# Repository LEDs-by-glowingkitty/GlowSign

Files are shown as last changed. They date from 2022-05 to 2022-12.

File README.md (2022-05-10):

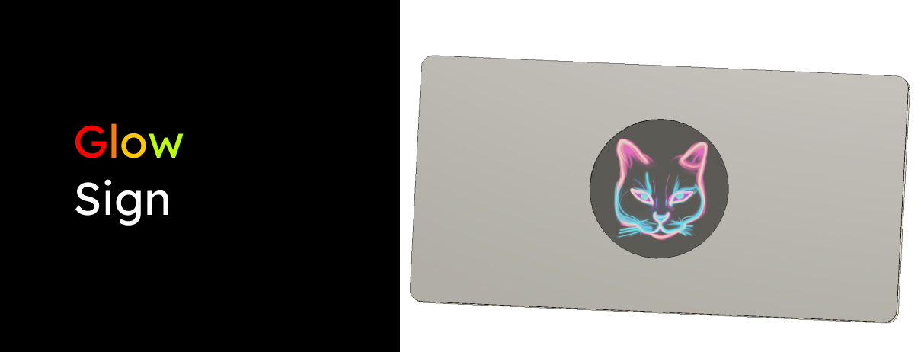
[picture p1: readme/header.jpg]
GlowSign


## Warning:

This project is currently under active development and has not been fully tested yet. If you decide to build or clone the project, be aware it might not work yet as expected. Use at your own risk.

## What is this project?

A battery powered LED sign for your laptop, or where ever else you want to use it!

## Links

- [Main PCB files](https://github.com/glowingkitty/GlowKittySign/tree/main/Main%20PCB)
- [Aluminum Cover PCB - Cat Edition files](https://github.com/glowingkitty/GlowKittySign/tree/main/AluminumCover%20PCB%20cat%20edition)

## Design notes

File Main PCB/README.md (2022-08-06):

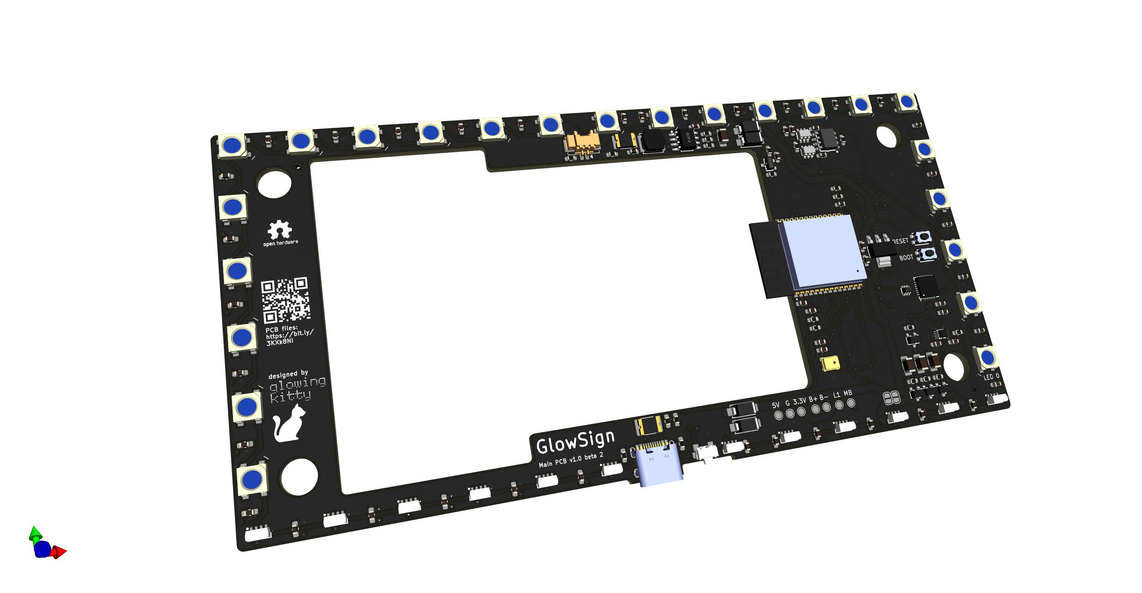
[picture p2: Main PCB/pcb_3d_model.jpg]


# GlowSign Main PCB

The main PCB for GlowSign. With all the LEDs, the integrated ESP32, a microphone to make the LED animations react to music - and it runs GlowOS (my WLED fork). But you can also upload your own software to the ESP32. The PCB can be powered via USB-C and via a lipo battery.

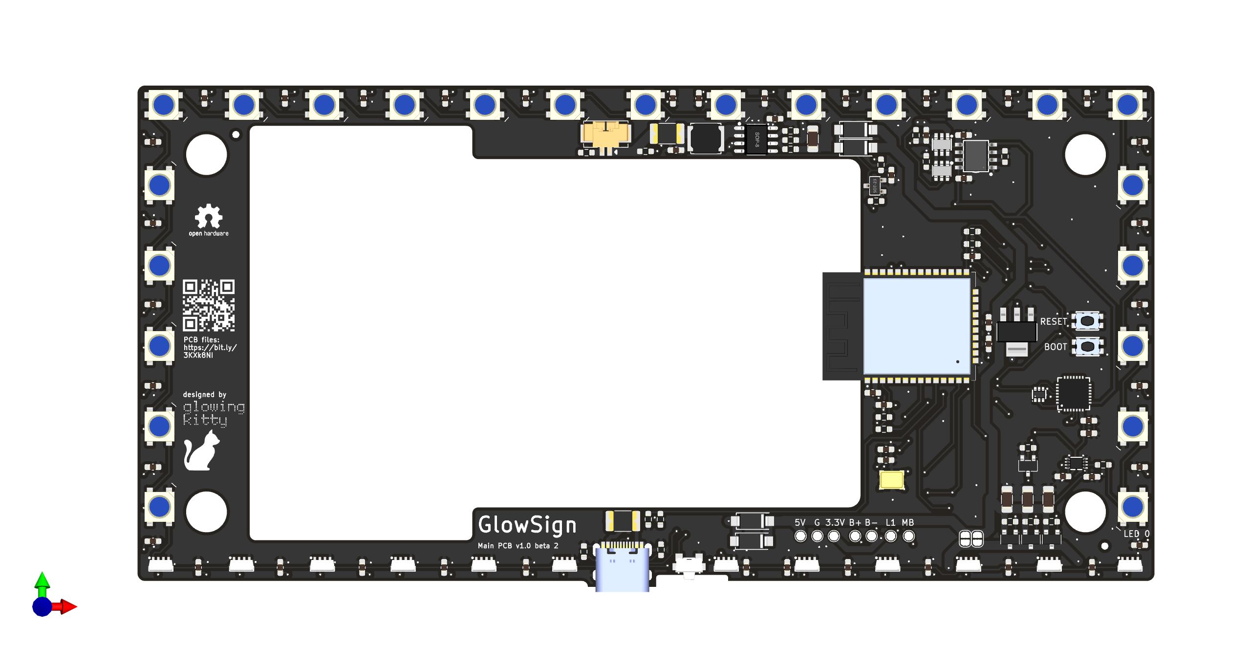
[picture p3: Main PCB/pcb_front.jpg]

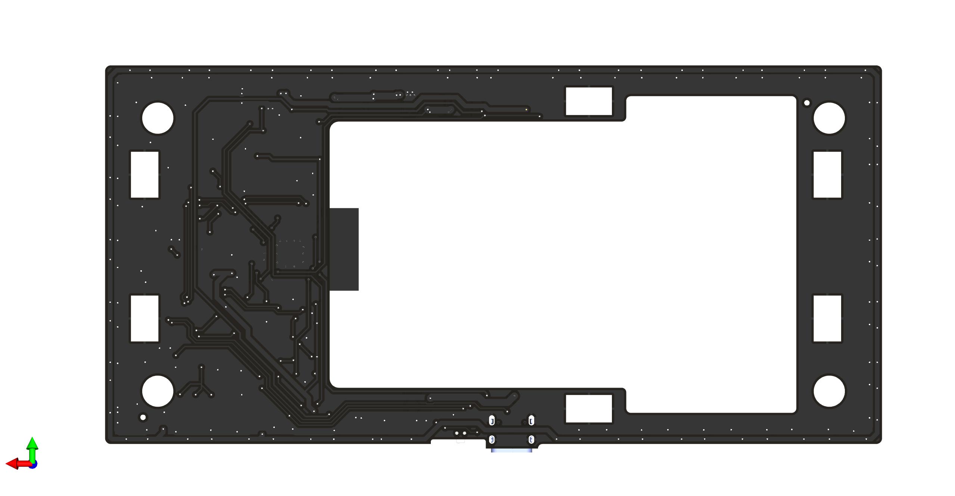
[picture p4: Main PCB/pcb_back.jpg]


## Links

- [Schematic](https://github.com/glowingkitty/GlowSign/blob/main/Main%20PCB/GlowSignMainPCB.pdf)
- [Interactive BOM](https://htmlpreview.github.io/?https://github.com/glowingkitty/GlowSign/blob/main/Main%20PCB/bom/ibom.html)

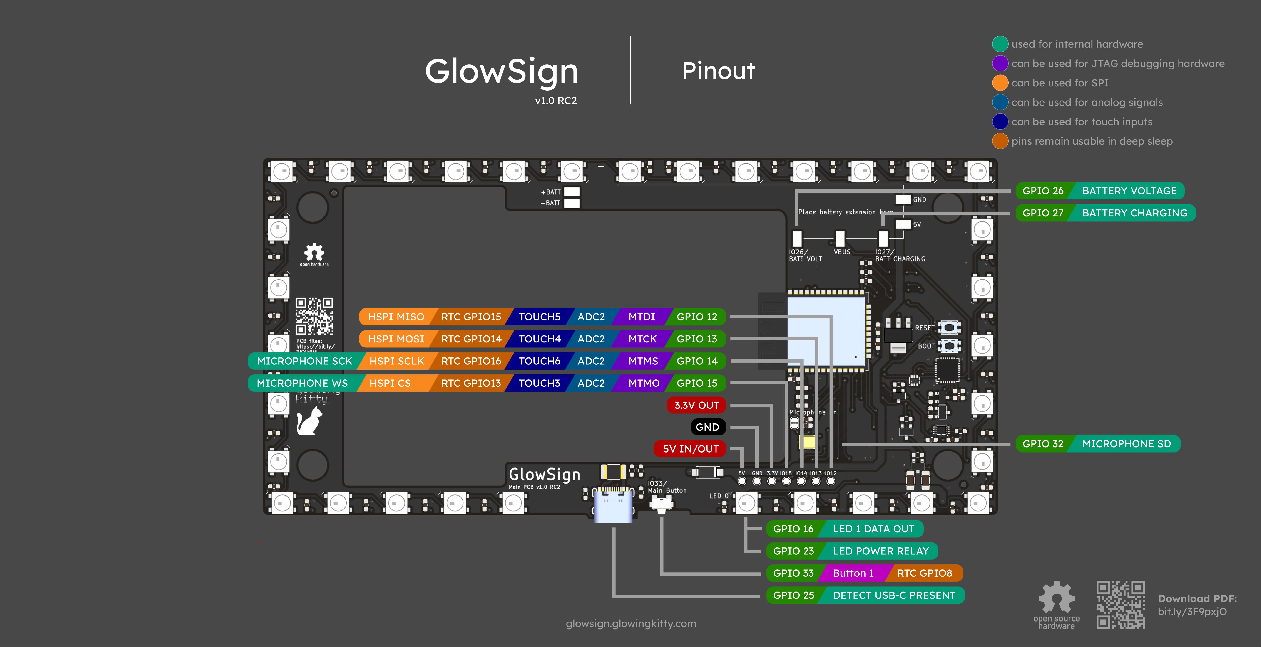
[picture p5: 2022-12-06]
documents/pinout GlowSign v1.0 RC2.jpg

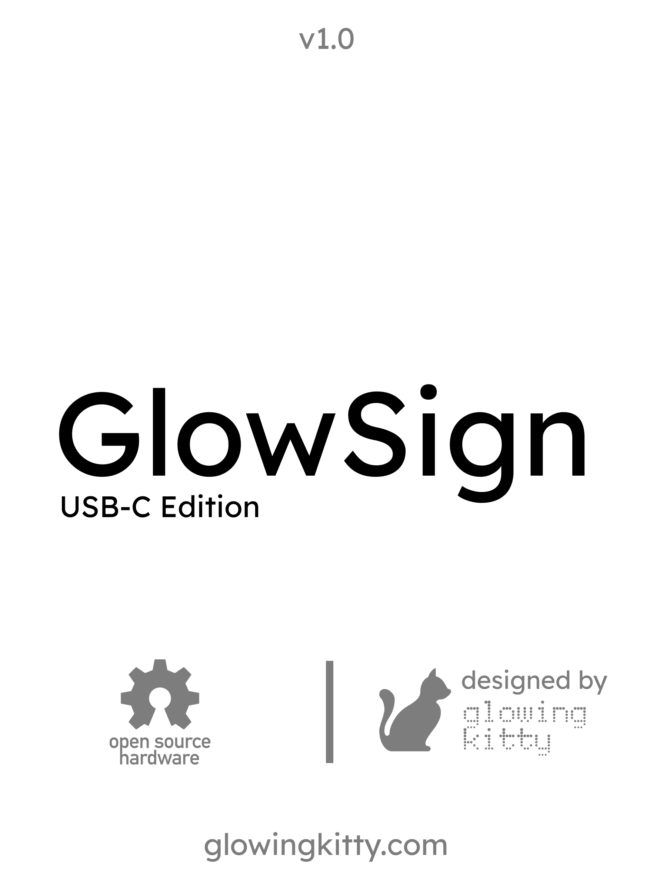
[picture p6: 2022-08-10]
GlowSign USB-C Sticker Back @300dpi (Page 1).png

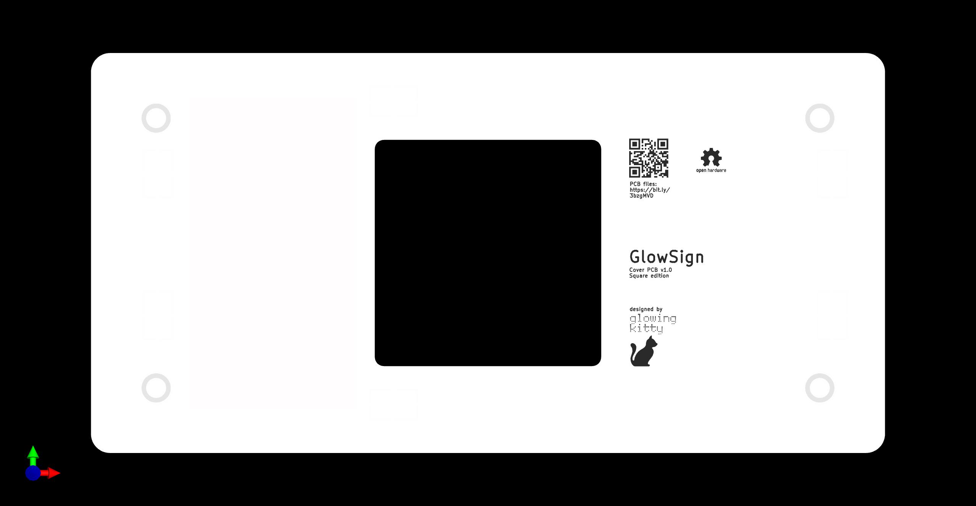
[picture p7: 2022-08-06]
Cover PCB Square Edition/pure_pcb_front.jpg

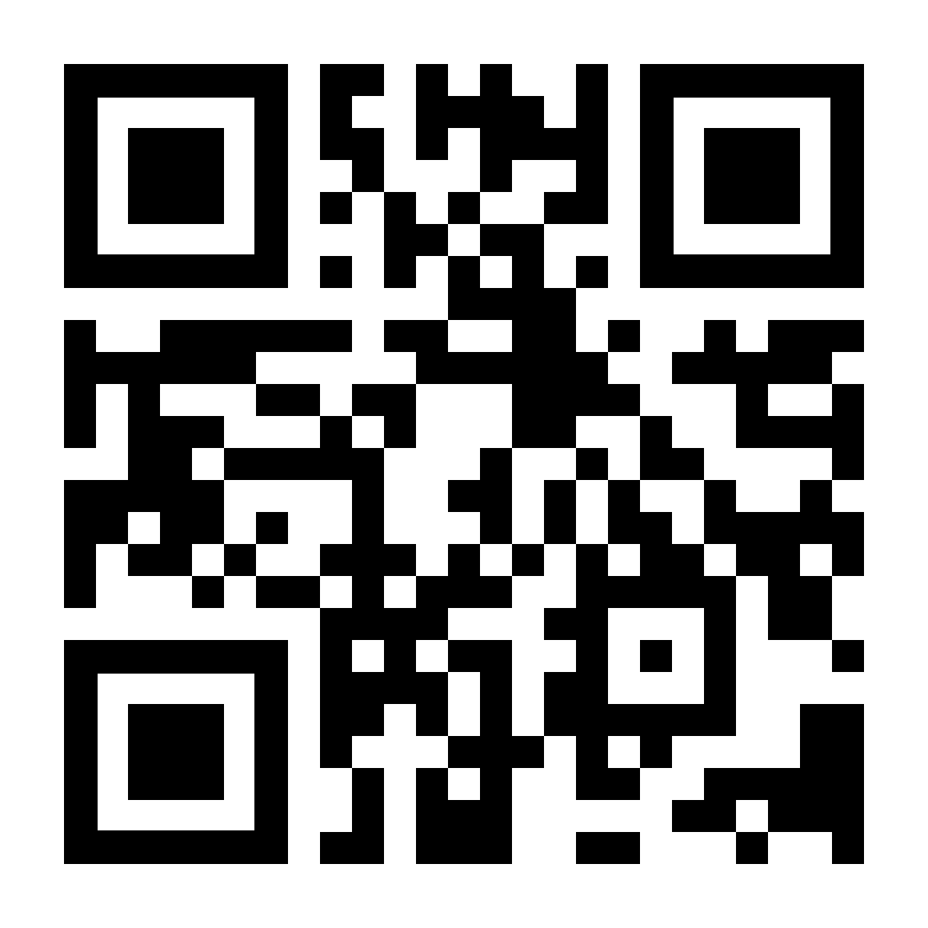
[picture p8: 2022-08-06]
Cover PCB Circle Edition/glowsign cover pcb circle pcb files.png

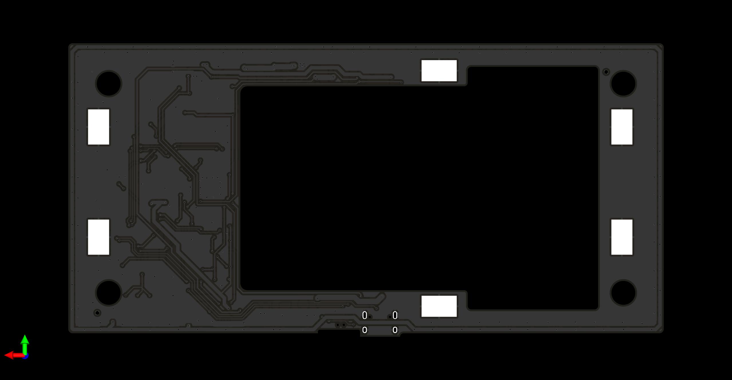
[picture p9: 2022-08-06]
Main PCB/pure_pcb_back.jpg

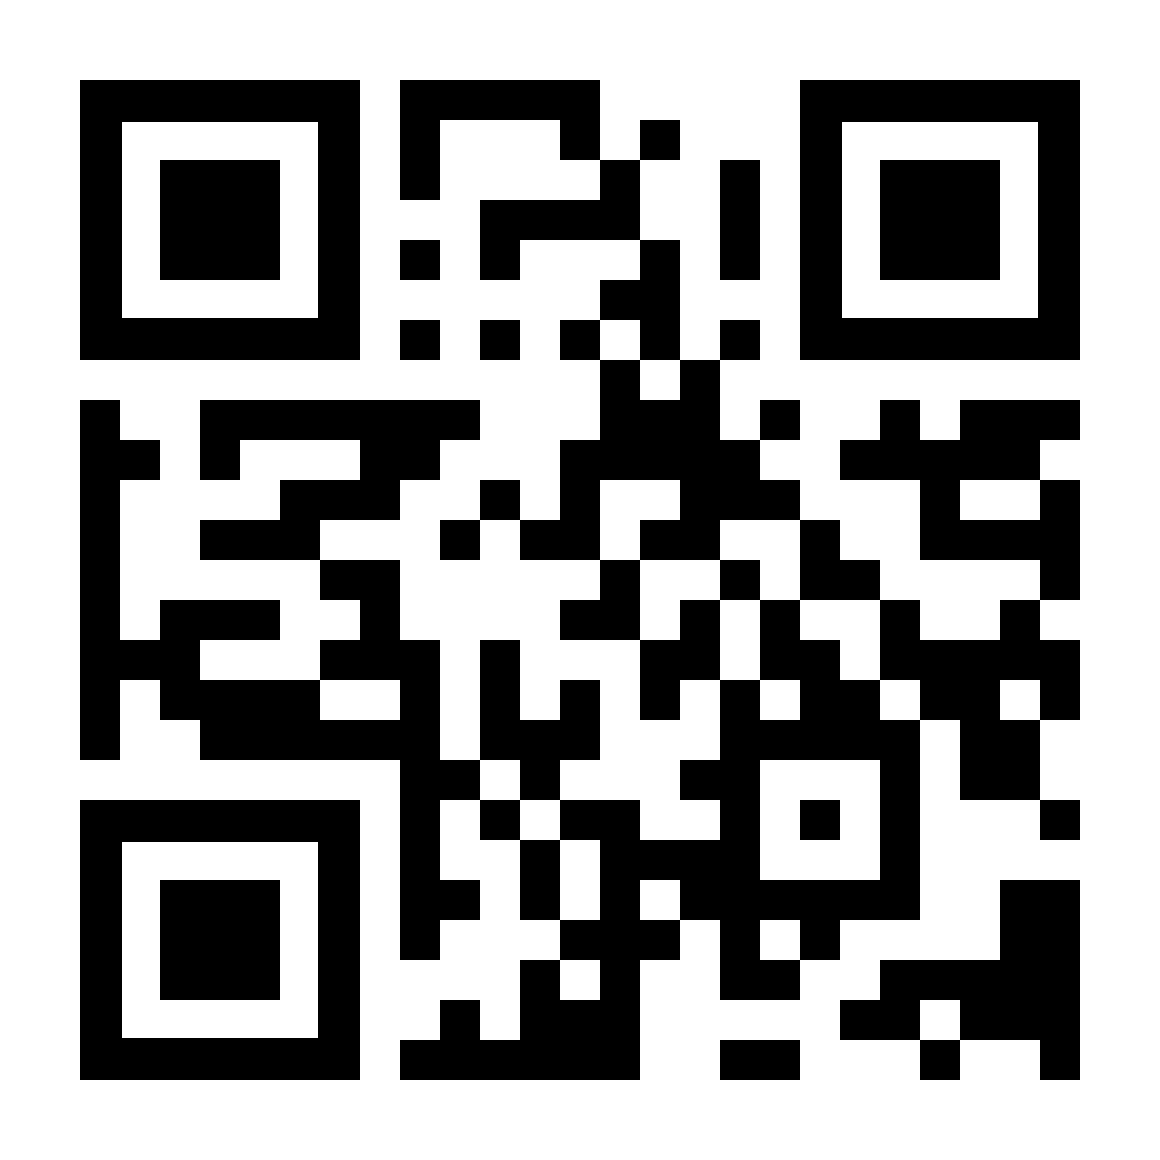
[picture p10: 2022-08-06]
Cover PCB Square Edition/glowsign cover square pcb files.png

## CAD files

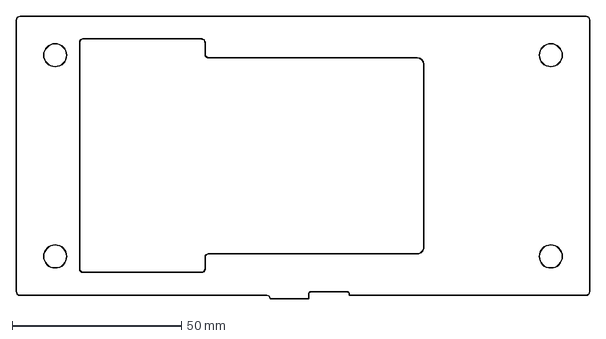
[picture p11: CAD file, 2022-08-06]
Main PCB/main_pcb_cutout.dxf
169.5 x 83.5 mm

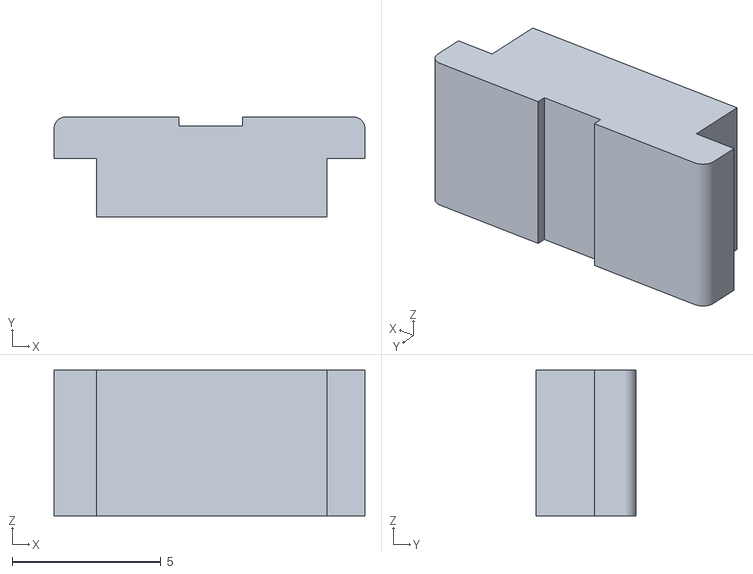
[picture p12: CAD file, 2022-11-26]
3D printed parts/main button.stl
10.4 x 3.37 x 4.89

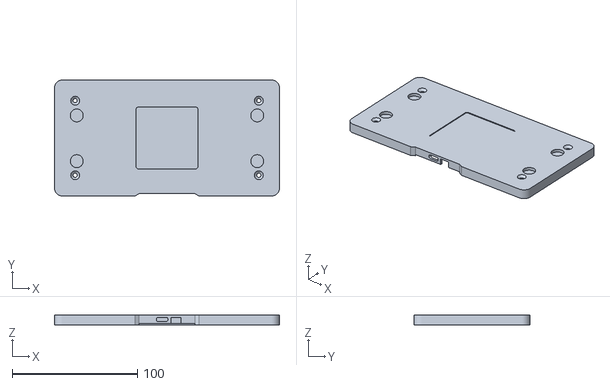
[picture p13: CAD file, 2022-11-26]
3D printed parts/case usb c only.stl
179.5 x 92.5 x 7.99

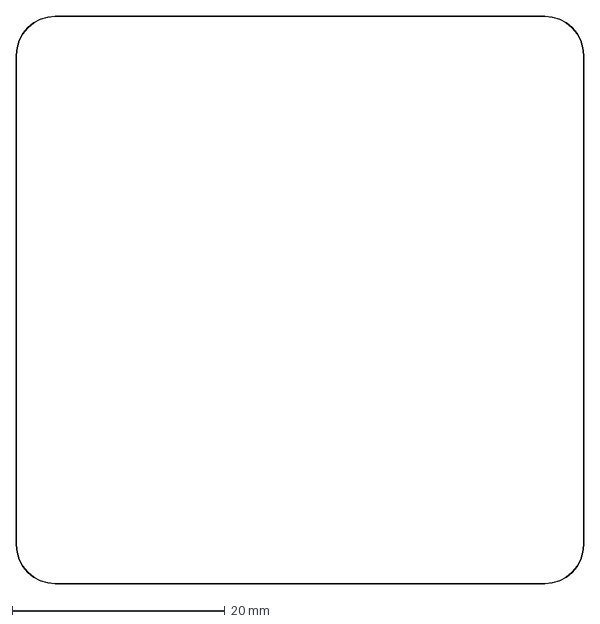
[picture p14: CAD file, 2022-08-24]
acrylic_plate_cutout.dxf
53.3 x 53.3 mm

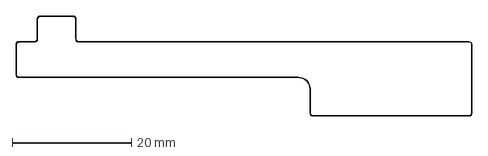
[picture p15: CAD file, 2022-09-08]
Battery Extension PCB/PCB cutout.dxf
76.5 x 16.7 mm

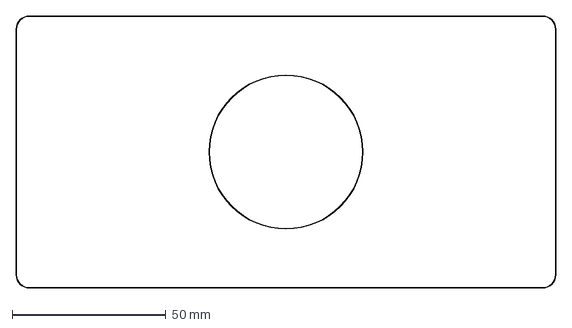
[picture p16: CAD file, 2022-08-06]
Cover PCB Circle Edition/aluminum_pcb_cutout_round.dxf
175.4 x 88.4 mm

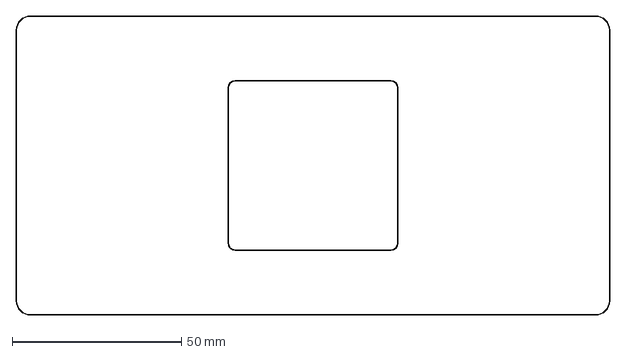
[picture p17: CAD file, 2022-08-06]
Cover PCB Square Edition/aluminum_pcb_cutout_square.dxf
175.4 x 88.4 mm

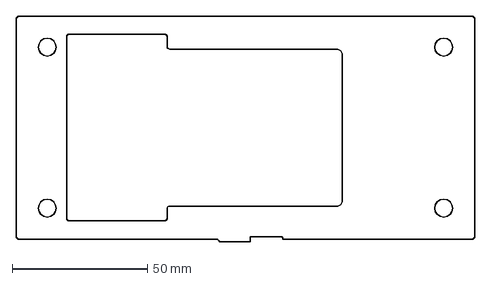
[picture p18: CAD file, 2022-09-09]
Main PCB/pcb_cutout.dxf
169.5 x 83.5 mm

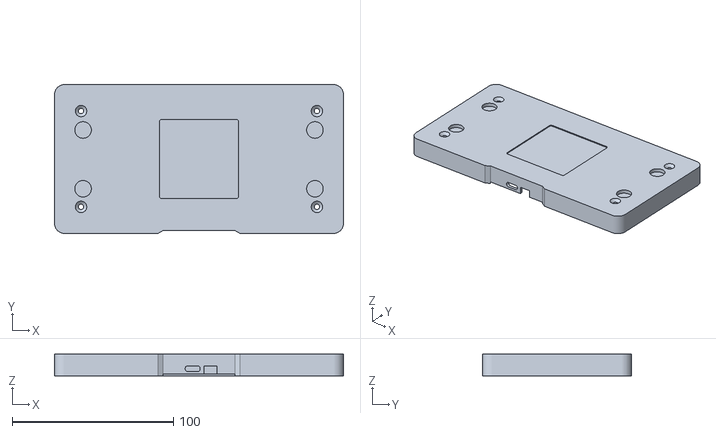
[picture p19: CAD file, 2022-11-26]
3D printed parts/case usb c and battery.stl
179.5 x 92.5 x 13.6

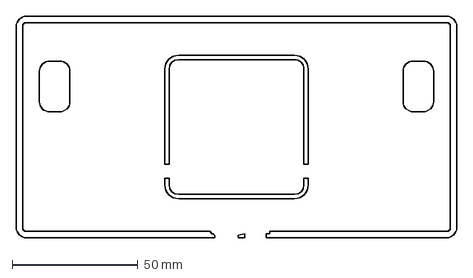
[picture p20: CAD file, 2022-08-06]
Main PCB/case_surrounding_pcb.dxf
175.0 x 88.0 mm

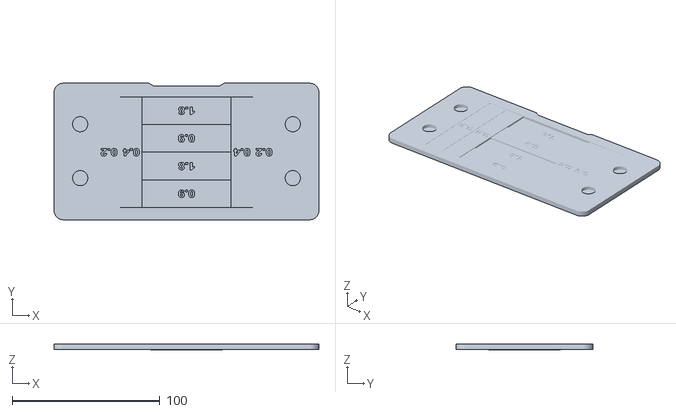
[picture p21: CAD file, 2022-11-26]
3D printed parts/magnetic dock.stl
179.5 x 92.5 x 4.30

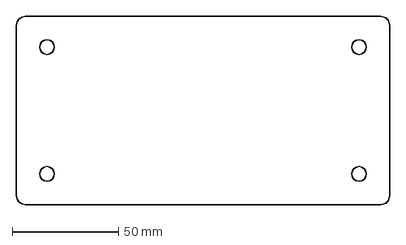
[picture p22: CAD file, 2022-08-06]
Cover PCB Circle Edition/aluminum_pcb_smd_nut_positions.dxf
175.4 x 88.4 mm

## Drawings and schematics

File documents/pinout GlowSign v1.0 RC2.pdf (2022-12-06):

GlowSign | Pinout

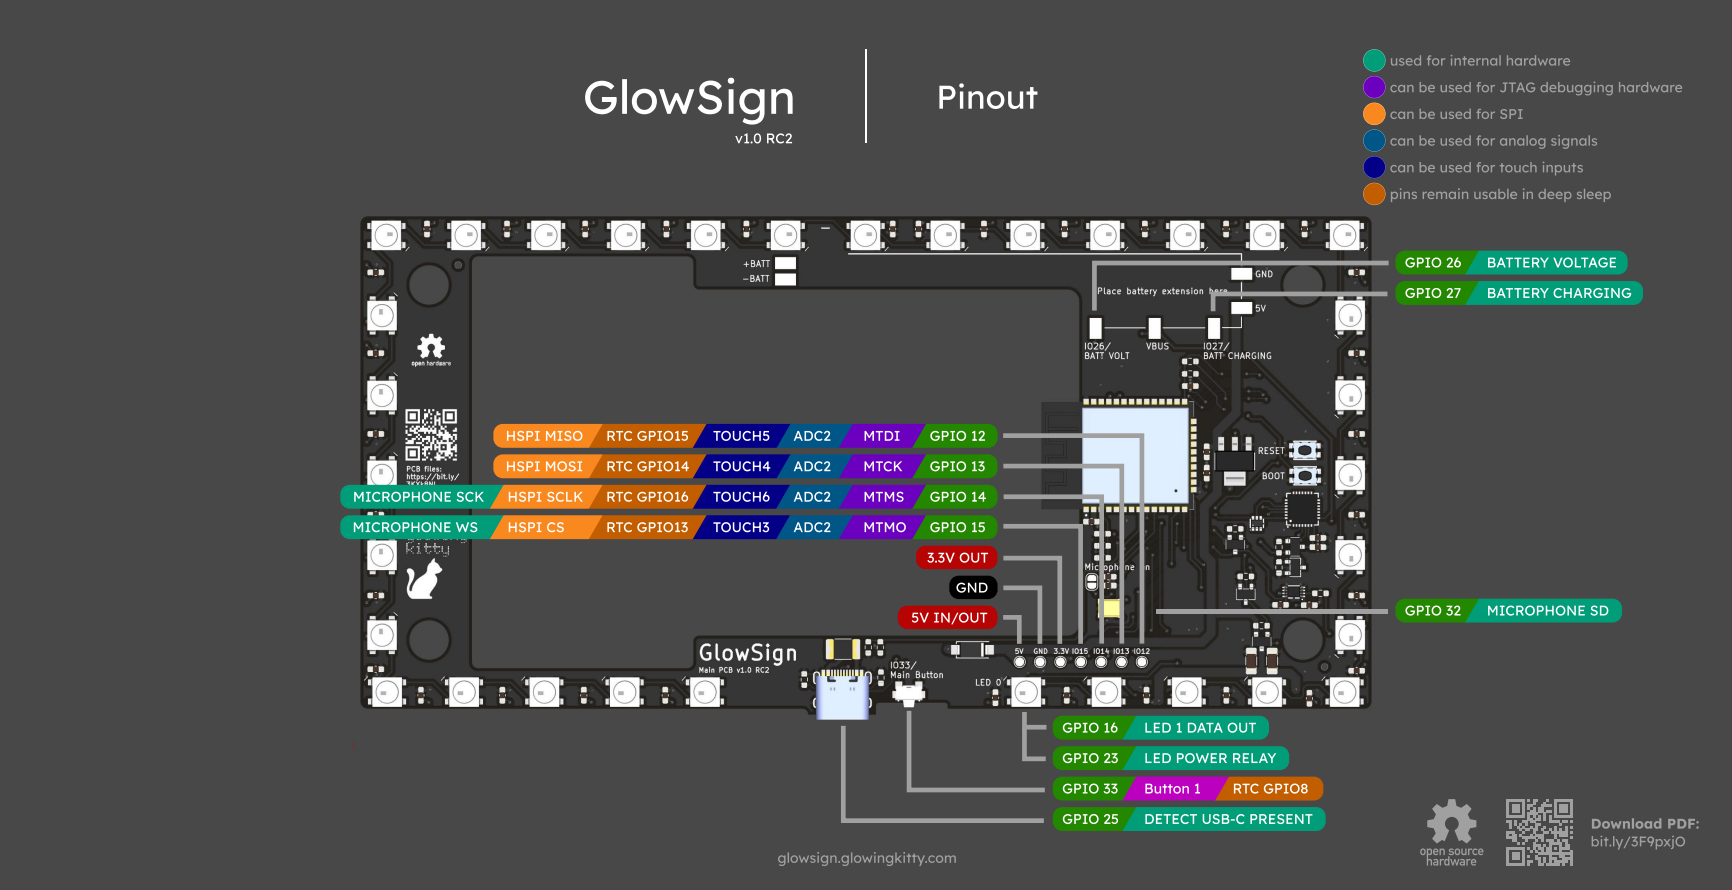
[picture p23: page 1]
GPIO 33; Button 1; RTC GPIO8; GPIO 23; LED POWER RELAY; GPIO 16; LED 1 DATA OUT; GPIO 32; MICROPHONE SD; GPIO 25; DETECT USB-C PRESENT; GPIO 26; BATTERY VOLTAGE; GPIO 27; BATTERY CHARGING; 3.3V OUT; 5V IN/OUT; GND; MICROPHONE SCK; HSPI SCLK; RTC GPIO16; TOUCH6; ADC2; MTMS; GPIO 14; MICROPHONE WS; HSPI CS; RTC GPIO13; TOUCH3; MTMO; GPIO 15; HSPI MISO; RTC GPIO15; TOUCH5; MTDI; GPIO 12; HSPI MOSI; RTC GPIO14; TOUCH4; MTCK; GPIO 13; Download PDF: bit.ly/3F9pxjO

used for internal hardware

can be used for JTAG debugging hardware

can be used for SPI

can be used for analog signals

can be used for touch inputs

pins remain usable in deep sleep

glowsign.glowingkitty.com

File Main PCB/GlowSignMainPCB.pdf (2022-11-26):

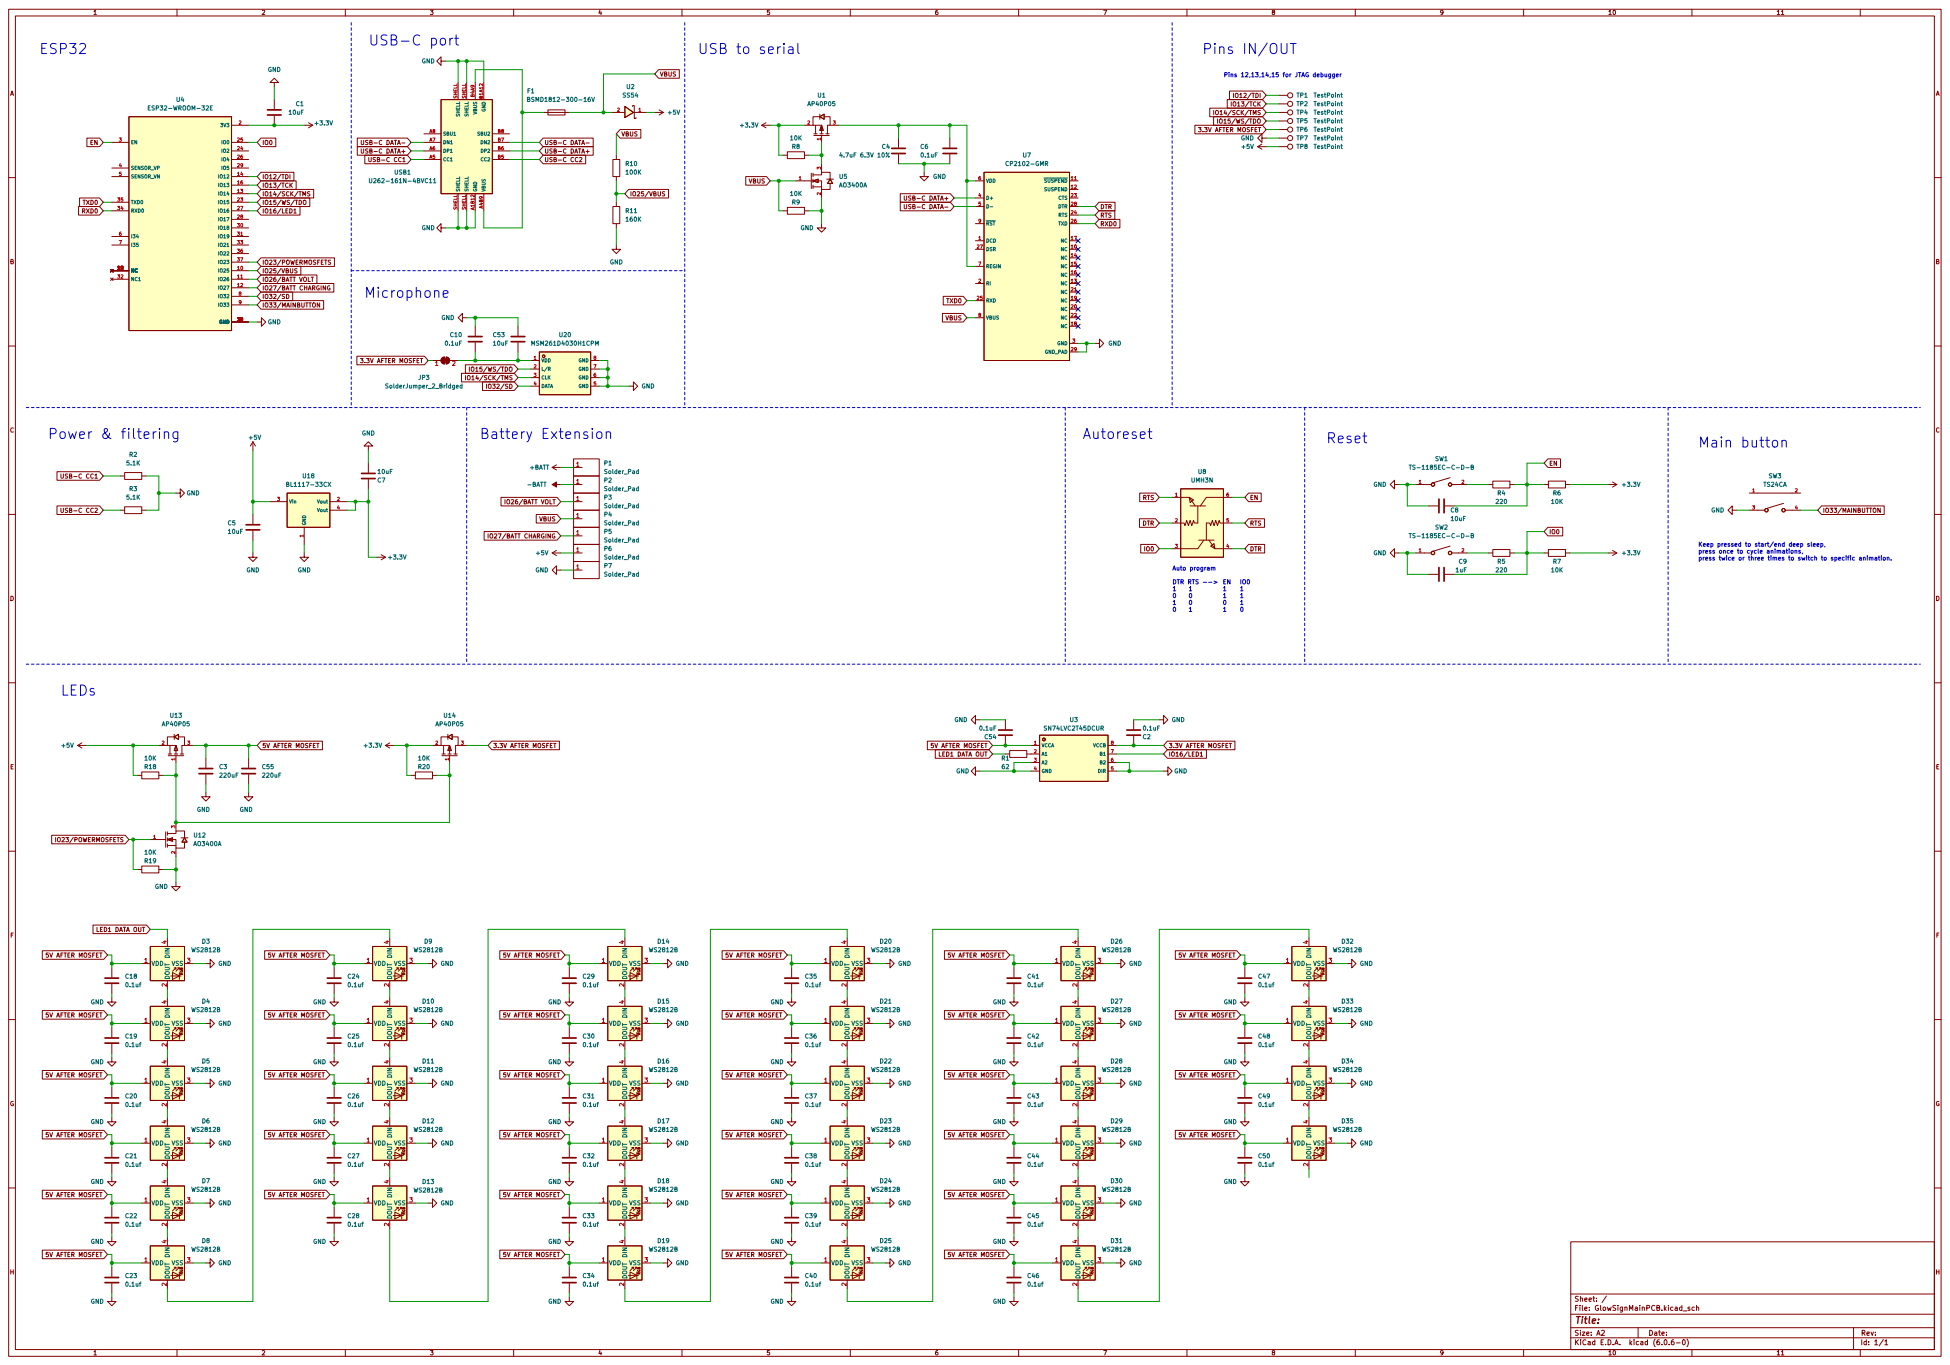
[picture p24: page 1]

USB to serial USB-C port ESP32

Pins 12,13,14,15 for JTAG debugger

4D14 WS2812BGND GND A1B12 VBUS A4B9 CC1 A5 DP1 A6 DN1 A7 SBU1 A8 GND B1A12 VBUS B4A9 CC2 B5 DP2 B6 DN2 B7 SBU2 B8 SHELL SHELL SHELL SHELL SHELL SHELL SHELL SHELL USB1 U262-161N-4BVC11 RGB VDD 1 DOUT

USB-C DATA+ USB-C CC1 USB-C DATA-

GND
3.3V AFTER MOSFET RTS DTR

1 Vout 2 Vin 3 Vout 4 U18 BL1117-33CX GND

Keep pressed to start/end deep sleep,
press once to cycle animations,
press twice or three times to switch to specific animation.

3 DIN
GND GND RGB VDD

4D10 WS2812BGND GND RGB VDD 1 DOUT

4D4 WS2812B GND RGB VDD 1 DOUT

4D28 WS2812B GND RGB VDD 1 DOUT

4D8 WS2812B GND RGB VDD 1 DOUT

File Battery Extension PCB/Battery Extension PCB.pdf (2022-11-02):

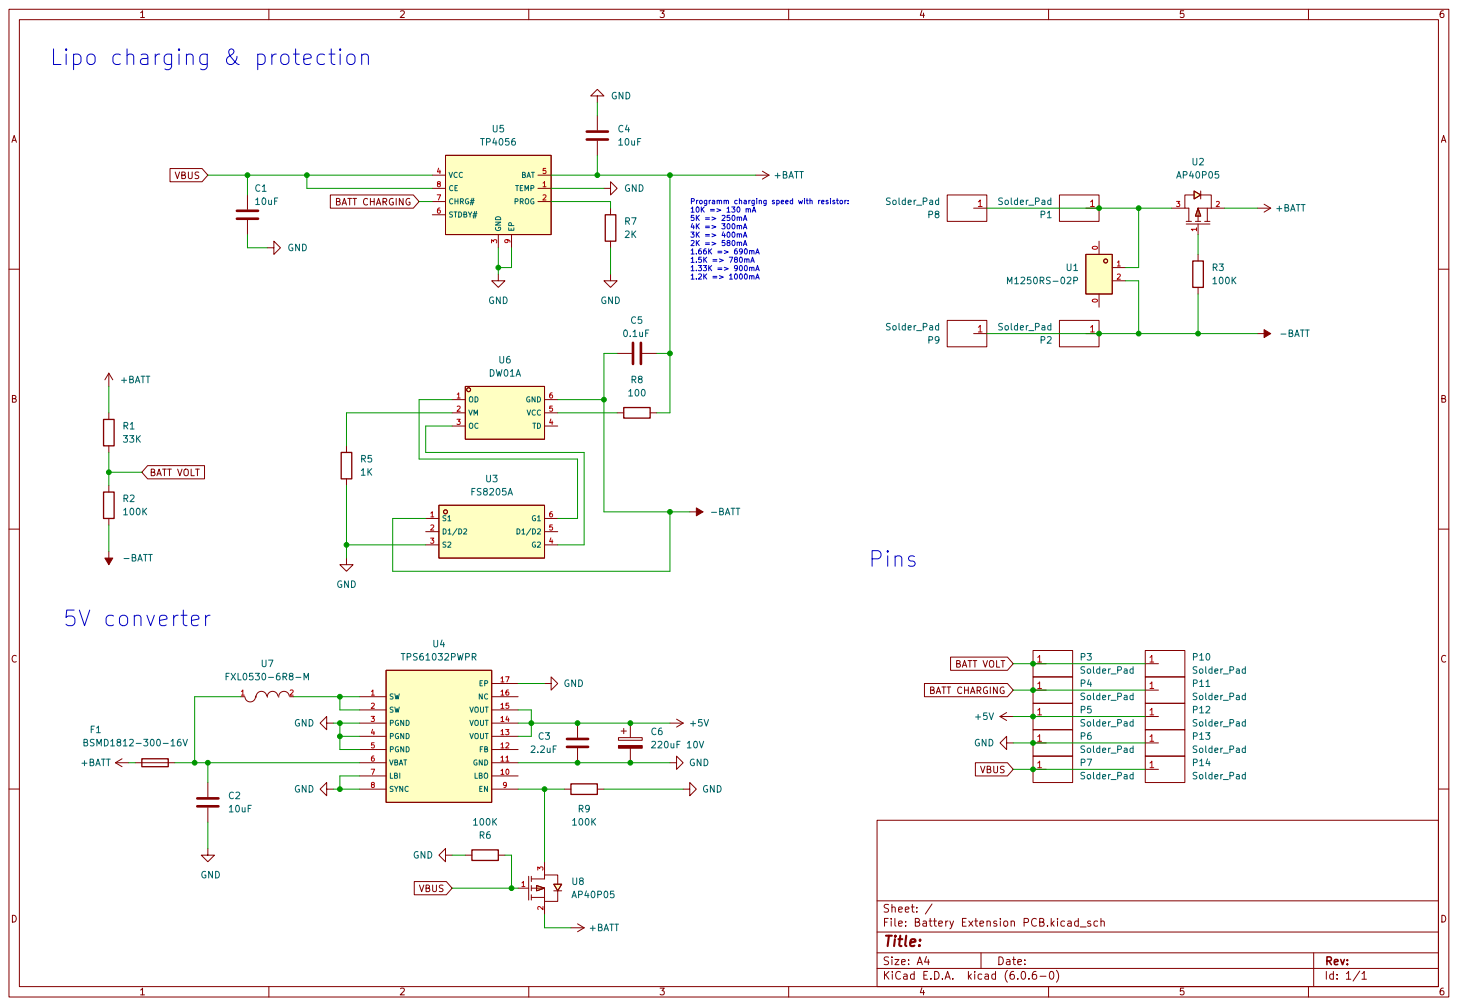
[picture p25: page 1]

BATT VOLT BATT CHARGING Lipo charging & protection

3 VCC 4 BAT 5 STDBY# 6 CHRG# 7 CE 8 EP

Programm charging speed with resistor: 10K => 130 mA 5K => 250mA

File: Battery Extension PCB.kicad_sch Sheet: / +5V GND

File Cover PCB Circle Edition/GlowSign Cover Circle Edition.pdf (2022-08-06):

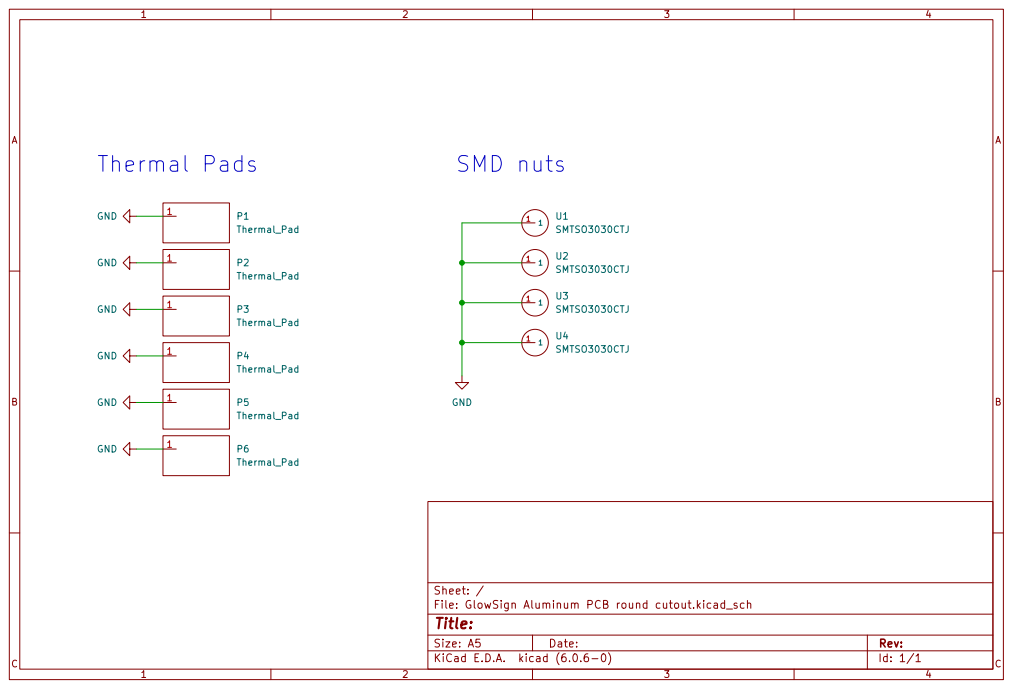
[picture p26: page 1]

File: GlowSign Aluminum PCB round cutout.kicad_sch Sheet: /

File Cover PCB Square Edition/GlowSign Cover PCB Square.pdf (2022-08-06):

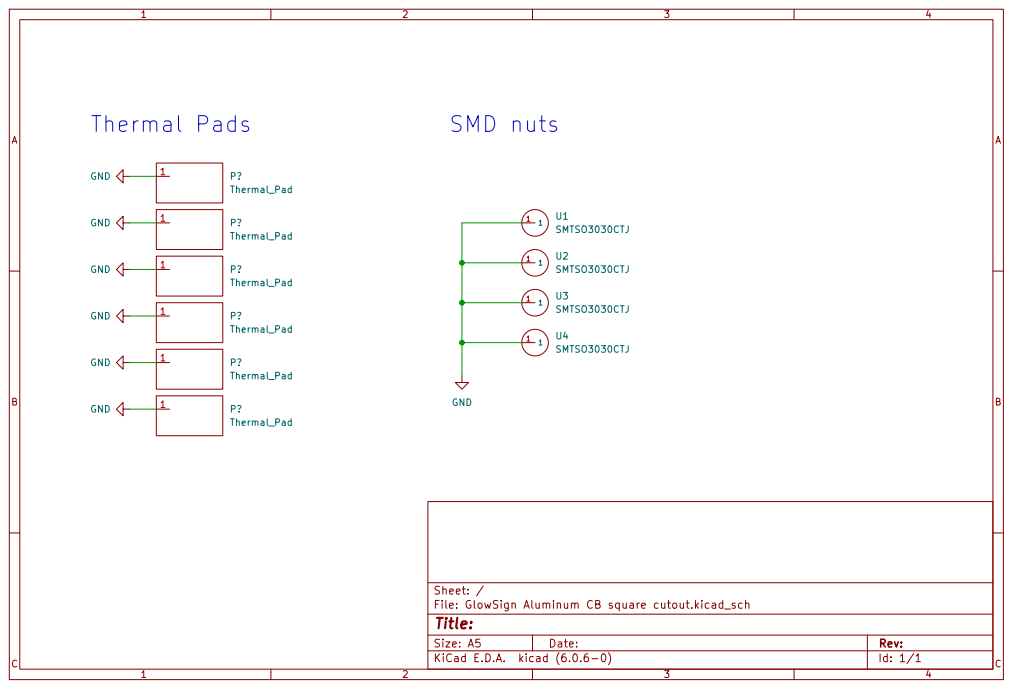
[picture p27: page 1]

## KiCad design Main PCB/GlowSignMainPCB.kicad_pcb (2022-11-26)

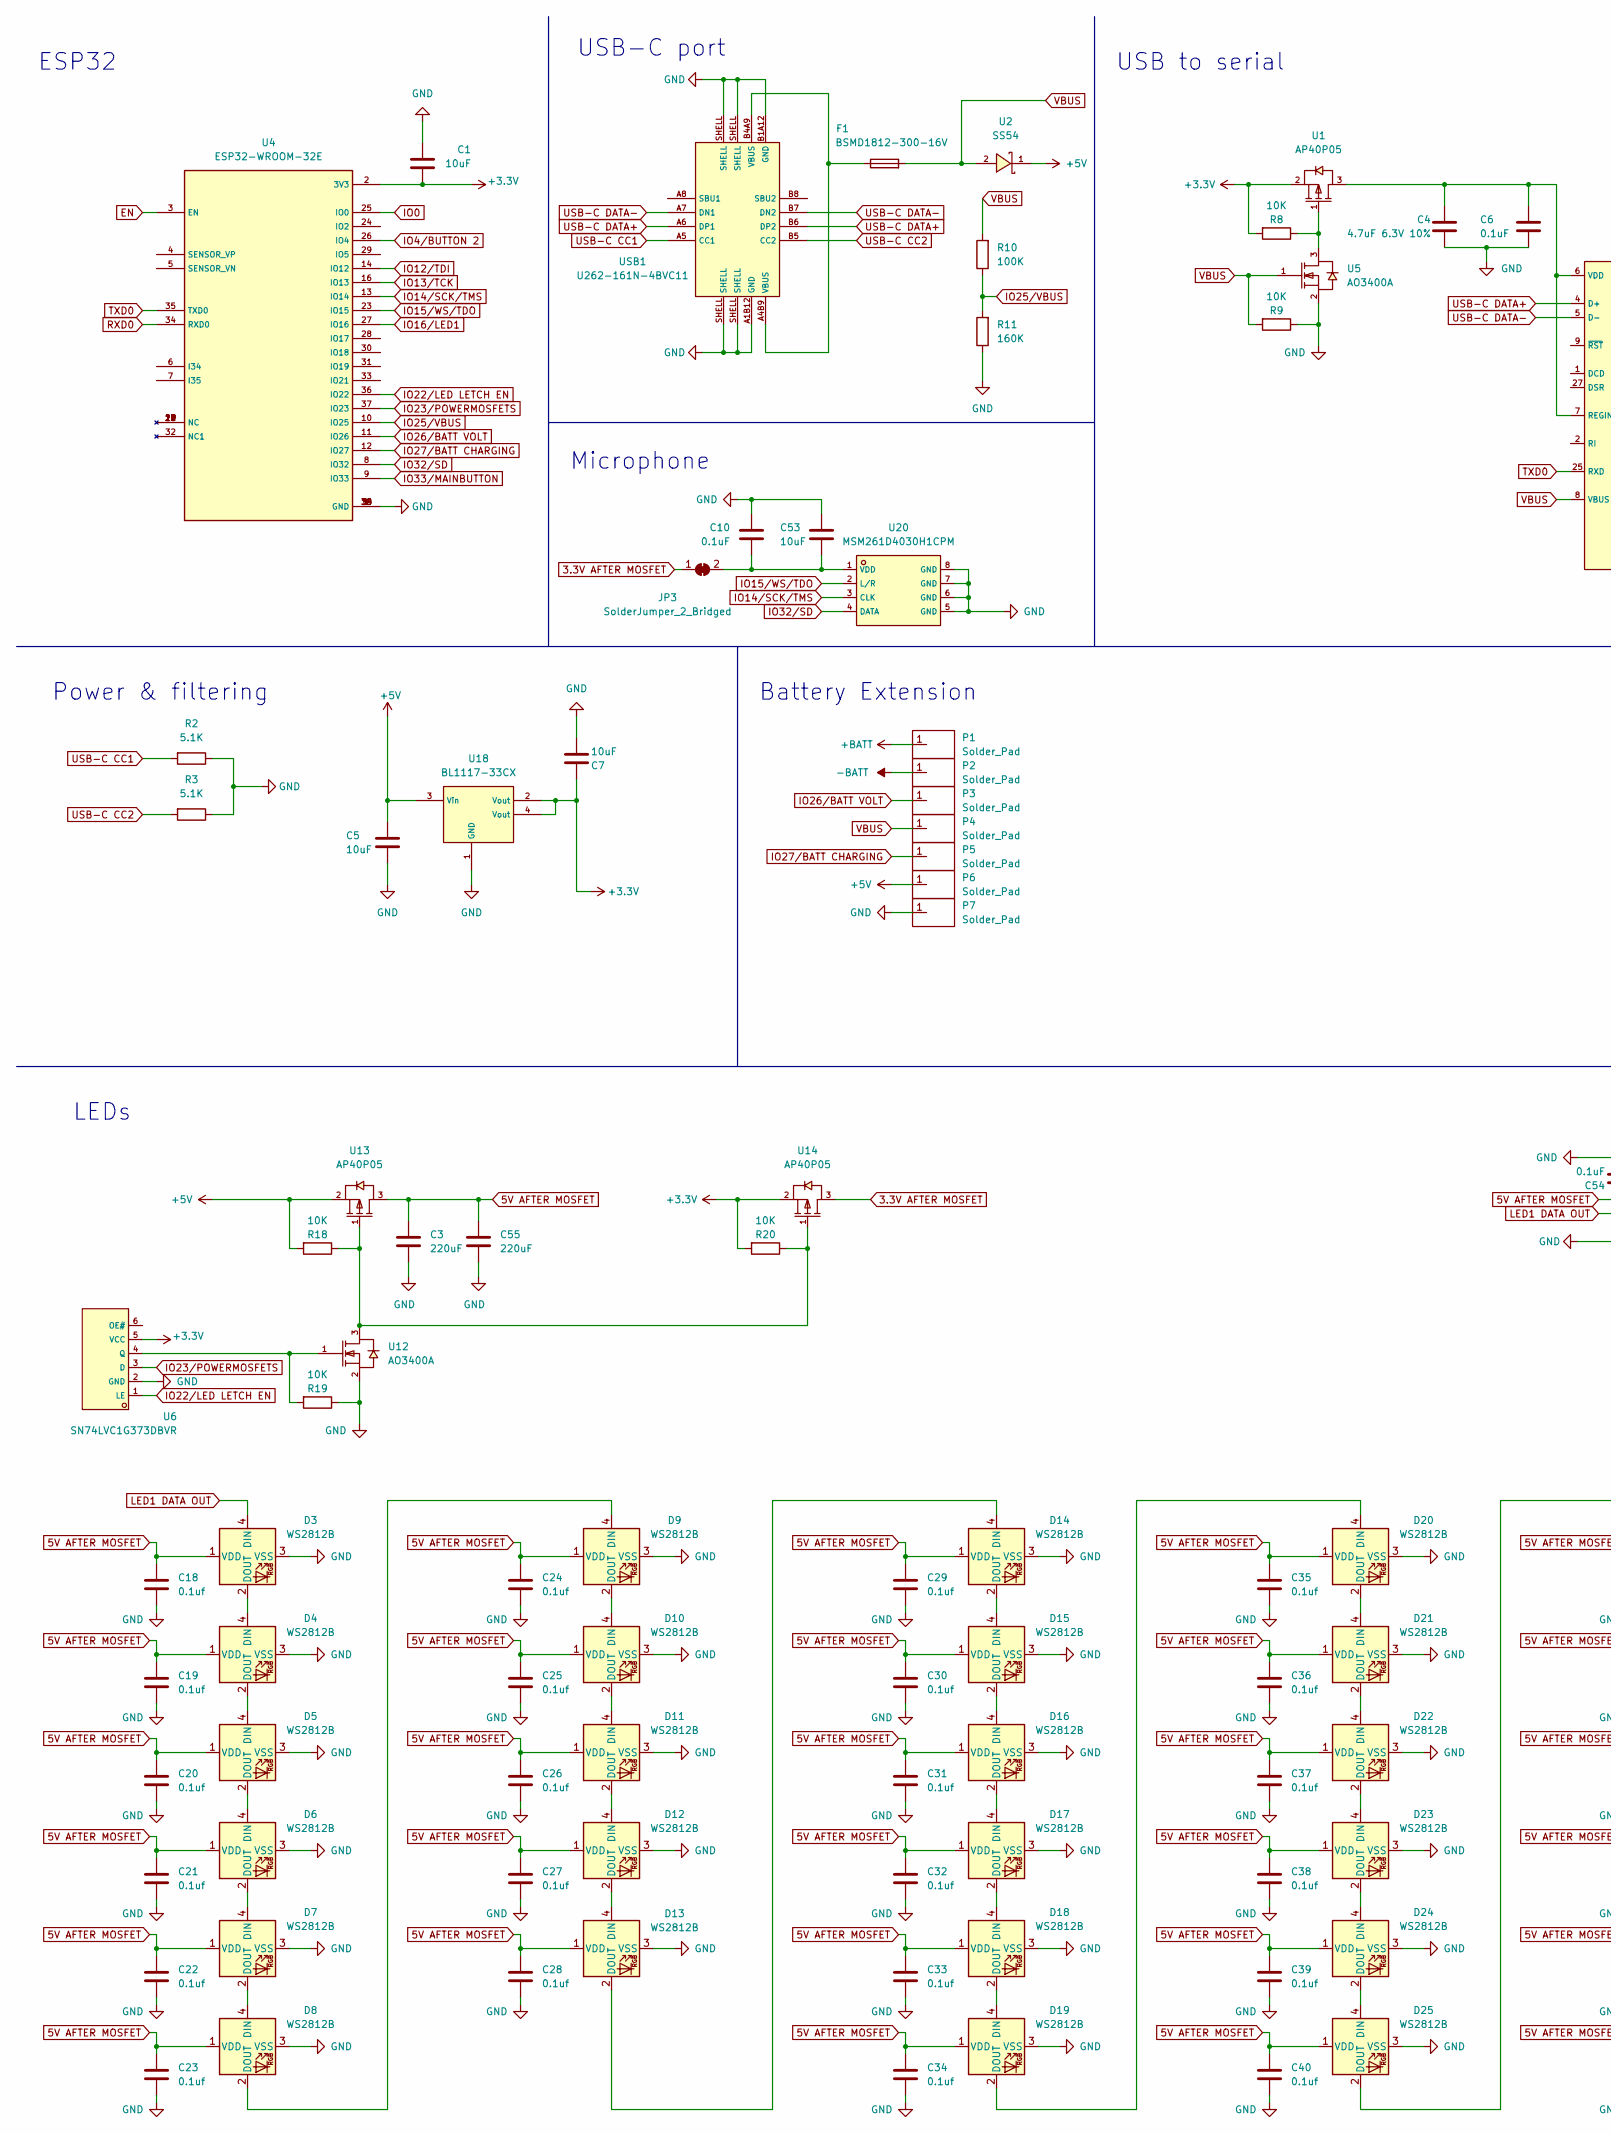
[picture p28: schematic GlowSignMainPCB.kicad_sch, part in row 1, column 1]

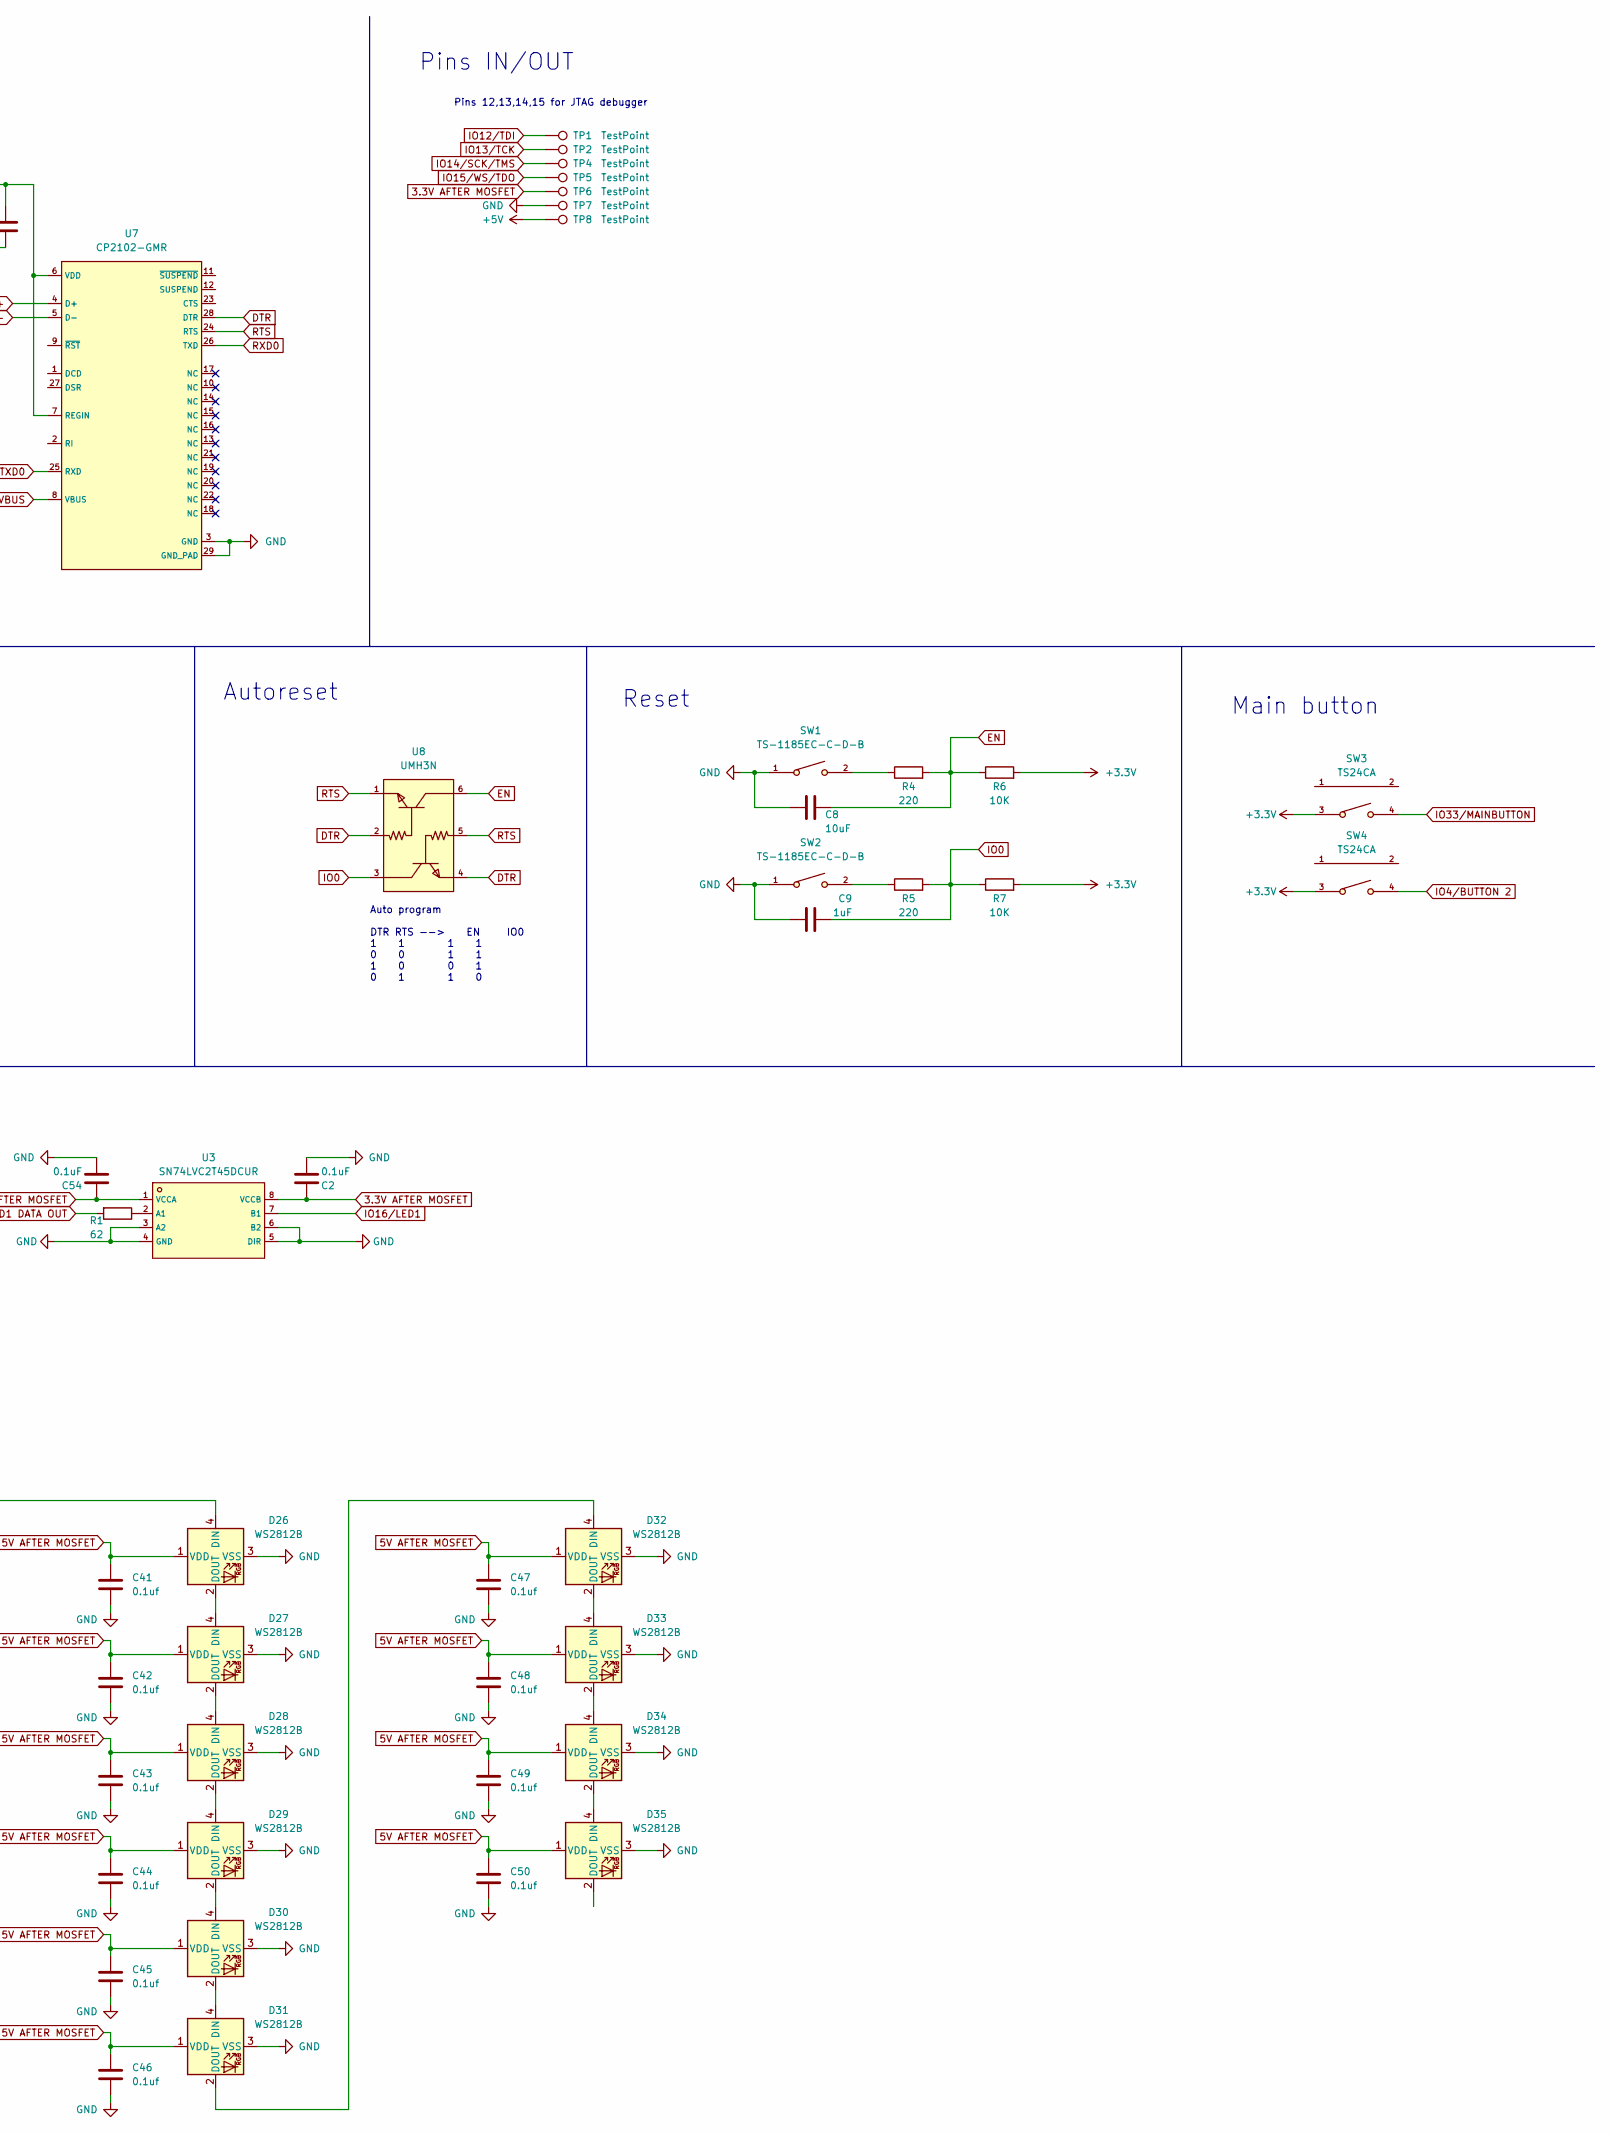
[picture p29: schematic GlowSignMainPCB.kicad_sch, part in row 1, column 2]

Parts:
C1, C5, C7, C8, C53: 10uF; C_0603_1608Metric_Pad1.08x0.95mm_HandSolder; LCSC # C19702
C2, C6, C10, C54: 0.1uF; C_0603_1608Metric_Pad1.08x0.95mm_HandSolder; LCSC # C14663
C3, C55: 220uF; C_1206_3216Metric_Pad1.33x1.80mm_HandSolder; LCSC # C412252
C4: 4.7uF 6.3V 10%; C_0603_1608Metric_Pad1.08x0.95mm_HandSolder; LCSC # C19666
C9: 1uF; C_0603_1608Metric_Pad1.08x0.95mm_HandSolder; LCSC # C15849
C18, C19, C20, C21, C22, C23, C24, C25, C26, C27, C28, C29, C30, C31, C32, C33, C34, C35, C36, C37, C38, C39, C40, C41, C42, C43, C44, C45, C46, C47, C48, C49, C50: 0.1uf; C_0603_1608Metric_Pad1.08x0.95mm_HandSolder; LCSC # C14663
D3, D4, D5, D6, D7, D8, D9, D10, D11, D12, D13, D14, D15, D16, D17, D18, D19, D20, D21, D22, D23, D24, D25, D26, D27, D28, D29, D30, D31, D32, D33, D34, D35: WS2812B; LED_WS2812B_PLCC4_5.0x5.0mm_P3.2mm; LCSC # C2843785
F1: BSMD1812-300-16V; Fuse_1812_4532Metric_Pad1.30x3.40mm_HandSolder; LCSC # C883162
JP3: SolderJumper_2_Bridged; SolderJumper-2_P1.3mm_Bridged_RoundedPad1.0x1.5mm
P1, P2, P3, P4, P5, P6, P7: Solder_Pad; Solder pad
R1: 62; R_0603_1608Metric_Pad0.98x0.95mm_HandSolder; LCSC # C177352
R2, R3: 5.1K; R_0603_1608Metric_Pad0.98x0.95mm_HandSolder; LCSC # C23186
R4, R5: 220; R_0603_1608Metric_Pad0.98x0.95mm_HandSolder; LCSC # C22962
R6, R7, R8, R9, R18, R19, R20: 10K; R_0603_1608Metric_Pad0.98x0.95mm_HandSolder; LCSC # C25804
R10: 100K; R_0603_1608Metric_Pad0.98x0.95mm_HandSolder; LCSC # C25803
R11: 160K; R_0603_1608Metric_Pad0.98x0.95mm_HandSolder; LCSC # C22813
SW1, SW2: TS-1185EC-C-D-B; SW-SMD_4P-L3.7-W3.0-P1.50-LS4.7; LCSC # C318893
SW3, SW4: TS24CA; SW-SMD_TS24CA; LCSC C393942
TP1, TP2, TP4, TP5, TP6, TP7, TP8: TestPoint; TestPoint_Pad_D1.5mm
U1, U13, U14: AP40P05; SOT-23-3_L2.9-W1.3-P1.90-LS2.4-BR; LCSC # C2886385
U2: SS54; SMA_L4.4-W2.8-LS5.4-RD; LCSC # C123946
U3: SN74LVC2T45DCUR; VSSOP-8_L2.4-W2.1-P0.50-LS3.2-BR; LCSC # C15741
U4: ESP32-WROOM-32E; WIFI-SMD_ESP32-WROOM-32E; LCSC # C701341
U5, U12: AO3400A; SOT-23-3_L2.9-W1.6-P1.90-LS2.8-BR; LCSC # C20917
U6: SN74LVC1G373DBVR; SOT-23-6_L2.9-W1.6-P0.95-LS2.8-BR; LCSC C128413
U7: CP2102-GMR; QFN-28_L5.0-W5.0-P0.50-BL-EP; LCSC # C6568
U8: UMH3N; SC-70-6_L2.2-W1.3-P0.65-LS2.1-BR; LCSC # C62892
U18: BL1117-33CX; SOT-223-4_L6.5-W3.5-P2.30-LS7.0-BR; LCSC # C5400
U20: MSM261D4030H1CPM; MIC-SMD_8P-L3.0-W4.0-P0.85-BL; LCSC # C966942
USB1: U262-161N-4BVC11; USB-3.1-SMD_U262-161N-4BVC11; LCSC # C319148

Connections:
3.3V AFTER MOSFET: C2.1, JP3.1 (A), TP6.1, U3.8 (VCCB), U14.3 (D)
5V AFTER MOSFET: C3.1, C18.1, C19.1, C20.1, C21.1, C22.1, C23.1, C24.1, C25.1, C26.1, C27.1, C28.1, C29.1, C30.1, C31.1, C32.1, C33.1, C34.1, C35.1, C36.1, C37.1, C38.1, C39.1, C40.1, C41.1, C42.1, C43.1, C44.1, C45.1, C46.1, C47.1, C48.1, C49.1, C50.1, C54.1, C55.1, D3.1 (VDD), D4.1 (VDD), D5.1 (VDD), D6.1 (VDD), D7.1 (VDD), D8.1 (VDD), D9.1 (VDD), D10.1 (VDD), D11.1 (VDD), D12.1 (VDD), D13.1 (VDD), D14.1 (VDD), D15.1 (VDD), D16.1 (VDD), D17.1 (VDD), D18.1 (VDD), D19.1 (VDD), D20.1 (VDD), D21.1 (VDD), D22.1 (VDD), D23.1 (VDD), D24.1 (VDD), D25.1 (VDD), D26.1 (VDD), D27.1 (VDD), D28.1 (VDD), D29.1 (VDD), D30.1 (VDD), D31.1 (VDD), D32.1 (VDD), D33.1 (VDD), D34.1 (VDD), D35.1 (VDD), U3.1 (VCCA), U13.3 (D)
+3V3: C1.2, C7.2, R6.2, R7.2, R8.2, R20.2, SW3.3, SW4.3, U1.2 (S), U4.2 (3V3), U6.5 (VCC), U14.2 (S), U18.2 (Vout), U18.4 (Vout)
+5V: C5.2, P6.1, R18.2, TP8.1, U2.1 (K), U13.2 (S), U18.3 (Vin)
+BATT: P1.1
-BATT: P2.1
DTR: U7.28 (DTR), U8.2 (B), U8.4 (E)
EN: C8.2, R4.2, R6.1, U4.3 (EN), U8.6 (C)
GND: C1.1, C2.2, C3.2, C4.1, C5.1, C6.2, C7.1, C8.1, C9.2, C10.1, C18.2, C19.2, C20.2, C21.2, C22.2, C23.2, C24.2, C25.2, C26.2, C27.2, C28.2, C29.2, C30.2, C31.2, C32.2, C33.2, C34.2, C35.2, C36.2, C37.2, C38.2, C39.2, C40.2, C41.2, C42.2, C43.2, C44.2, C45.2, C46.2, C47.2, C48.2, C49.2, C50.2, C53.1, C54.2, C55.2, D3.3 (VSS), D4.3 (VSS), D5.3 (VSS), D6.3 (VSS), D7.3 (VSS), D8.3 (VSS), D9.3 (VSS), D10.3 (VSS), D11.3 (VSS), D12.3 (VSS), D13.3 (VSS), D14.3 (VSS), D15.3 (VSS), D16.3 (VSS), D17.3 (VSS), D18.3 (VSS), D19.3 (VSS), D20.3 (VSS), D21.3 (VSS), D22.3 (VSS), D23.3 (VSS), D24.3 (VSS), D25.3 (VSS), D26.3 (VSS), D27.3 (VSS), D28.3 (VSS), D29.3 (VSS), D30.3 (VSS), D31.3 (VSS), D32.3 (VSS), D33.3 (VSS), D34.3 (VSS), D35.3 (VSS), P7.1, R2.1, R3.1, R9.1, R11.1, R19.1, SW1.1, SW2.1, TP7.1, U3.3 (A2), U3.4 (GND), U3.5 (DIR), U3.6 (B2), U4.1 (GND), U4.15 (GND), U4.38 (GND), U4.39 (GND), U5.2 (S), U6.2 (GND), U7.3 (GND), U7.29 (GND_PAD), U12.2 (S), U18.1 (GND), U20.5 (GND), U20.6 (GND), U20.7 (GND), U20.8 (GND), USB1.A1B12 (GND), USB1.B1A12 (GND), USB1.SHELL
IO0: C9.1, R5.2, R7.1, U4.25 (IO0), U8.3 (C)
IO4/BUTTON 2: SW4.4, U4.26 (IO4)
IO12/TDI: TP1.1, U4.14 (IO12)
IO13/TCK: TP2.1, U4.16 (IO13)
IO14/SCK/TMS: TP4.1, U4.13 (IO14), U20.3 (CLK)
IO15/WS/TDO: TP5.1, U4.23 (IO15), U20.2 (L/R)
IO16/LED1: U3.7 (B1), U4.27 (IO16)
IO22/LED LETCH EN: U4.36 (IO22), U6.1 (LE)
IO23/POWERMOSFETS: U4.37 (IO23), U6.3 (D)
IO25/VBUS: R10.1, R11.2, U4.10 (IO25)
IO26/BATT VOLT: P3.1, U4.11 (IO26)
IO27/BATT CHARGING: P5.1, U4.12 (IO27)
IO32/SD: U4.8 (IO32), U20.4 (DATA)
IO33/MAINBUTTON: SW3.4, U4.9 (IO33)
LED1 DATA OUT: D3.4 (DIN), R1.2
unnamed: C4.2, C6.1, U1.3 (D), U7.6 (VDD), U7.7 (REGIN)
unnamed: C10.2, C53.2, JP3.2 (B), U20.1 (VDD)
unnamed: D3.2 (DOUT), D4.4 (DIN)
unnamed: D4.2 (DOUT), D5.4 (DIN)
unnamed: D5.2 (DOUT), D6.4 (DIN)
unnamed: D6.2 (DOUT), D7.4 (DIN)
unnamed: D7.2 (DOUT), D8.4 (DIN)
unnamed: D8.2 (DOUT), D9.4 (DIN)
unnamed: D10.2 (DOUT), D11.4 (DIN)
unnamed: D9.2 (DOUT), D10.4 (DIN)
unnamed: D11.2 (DOUT), D12.4 (DIN)
unnamed: D12.2 (DOUT), D13.4 (DIN)
unnamed: D13.2 (DOUT), D14.4 (DIN)
unnamed: D14.2 (DOUT), D15.4 (DIN)
unnamed: D15.2 (DOUT), D16.4 (DIN)
unnamed: D16.2 (DOUT), D17.4 (DIN)
unnamed: D17.2 (DOUT), D18.4 (DIN)
unnamed: D18.2 (DOUT), D19.4 (DIN)
unnamed: D19.2 (DOUT), D20.4 (DIN)
unnamed: D20.2 (DOUT), D21.4 (DIN)
unnamed: D21.2 (DOUT), D22.4 (DIN)
unnamed: D22.2 (DOUT), D23.4 (DIN)
unnamed: D23.2 (DOUT), D24.4 (DIN)
unnamed: D24.2 (DOUT), D25.4 (DIN)
unnamed: D25.2 (DOUT), D26.4 (DIN)
unnamed: D26.2 (DOUT), D27.4 (DIN)
unnamed: D27.2 (DOUT), D28.4 (DIN)
unnamed: D28.2 (DOUT), D29.4 (DIN)
unnamed: D29.2 (DOUT), D30.4 (DIN)
unnamed: D30.2 (DOUT), D31.4 (DIN)
unnamed: D31.2 (DOUT), D32.4 (DIN)
unnamed: D32.2 (DOUT), D33.4 (DIN)
unnamed: D33.2 (DOUT), D34.4 (DIN)
unnamed: D34.2 (DOUT), D35.4 (DIN)
unnamed: F1.1, USB1.A4B9 (VBUS), USB1.B4A9 (VBUS)
unnamed: R1.1, U3.2 (A1)
unnamed: R4.1, SW1.2
unnamed: R5.1, SW2.2
unnamed: R8.1, U1.1 (G), U5.3 (D)
unnamed: R18.1, R20.1, U12.3 (D), U13.1 (G), U14.1 (G)
unnamed: R19.2, U6.4 (Q), U12.1 (G)
RTS: U7.24 (RTS), U8.1 (E), U8.5 (B)
RXD0: U4.34 (RXD0), U7.26 (TXD)
TXD0: U4.35 (TXD0), U7.25 (RXD)
USB-C CC1: R2.2, USB1.A5 (CC1)
USB-C CC2: R3.2, USB1.B5 (CC2)
USB-C DATA+: U7.4 (D+), USB1.A6 (DP1), USB1.B6 (DP2)
USB-C DATA-: U7.5 (D-), USB1.A7 (DN1), USB1.B7 (DN2)
VBUS: F1.2, P4.1, R9.2, R10.2, U2.2 (A), U5.1 (G), U7.8 (VBUS)

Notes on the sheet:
Auto program DTR RTS --> EN IO0 1 1 1 1 0 0 1 1 1 0 0 1 0 1 1 0
Autoreset
USB to serial
Reset
USB-C port
Power & filtering
Pins 12,13,14,15 for JTAG debugger
Main button
ESP32
Battery Extension
LEDs
Microphone
Pins IN/OUT

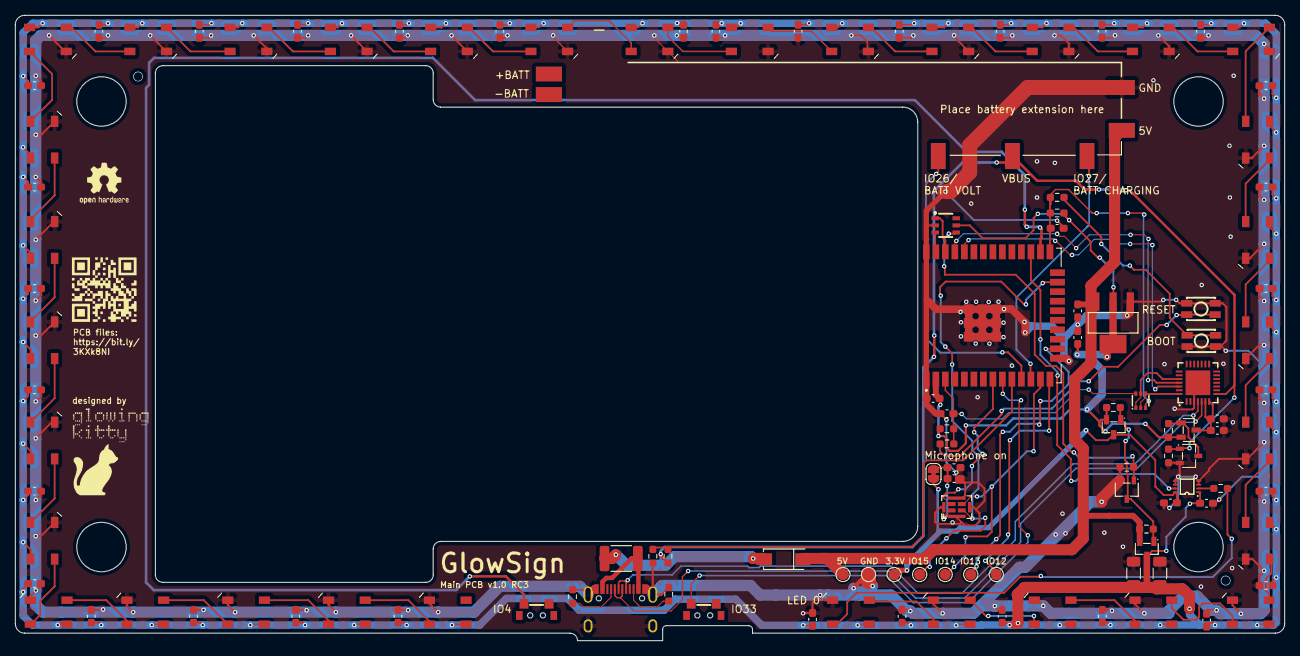
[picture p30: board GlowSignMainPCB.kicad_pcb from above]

Board: 2 copper layers, 169.5 x 83.5 mm, 130 parts (0 on the bottom side), 71 nets.

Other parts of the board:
OSHW logo: OSHW-Logo2_7.3x6mm_SilkScreen
logo: LOGO
qrcode: LOGO

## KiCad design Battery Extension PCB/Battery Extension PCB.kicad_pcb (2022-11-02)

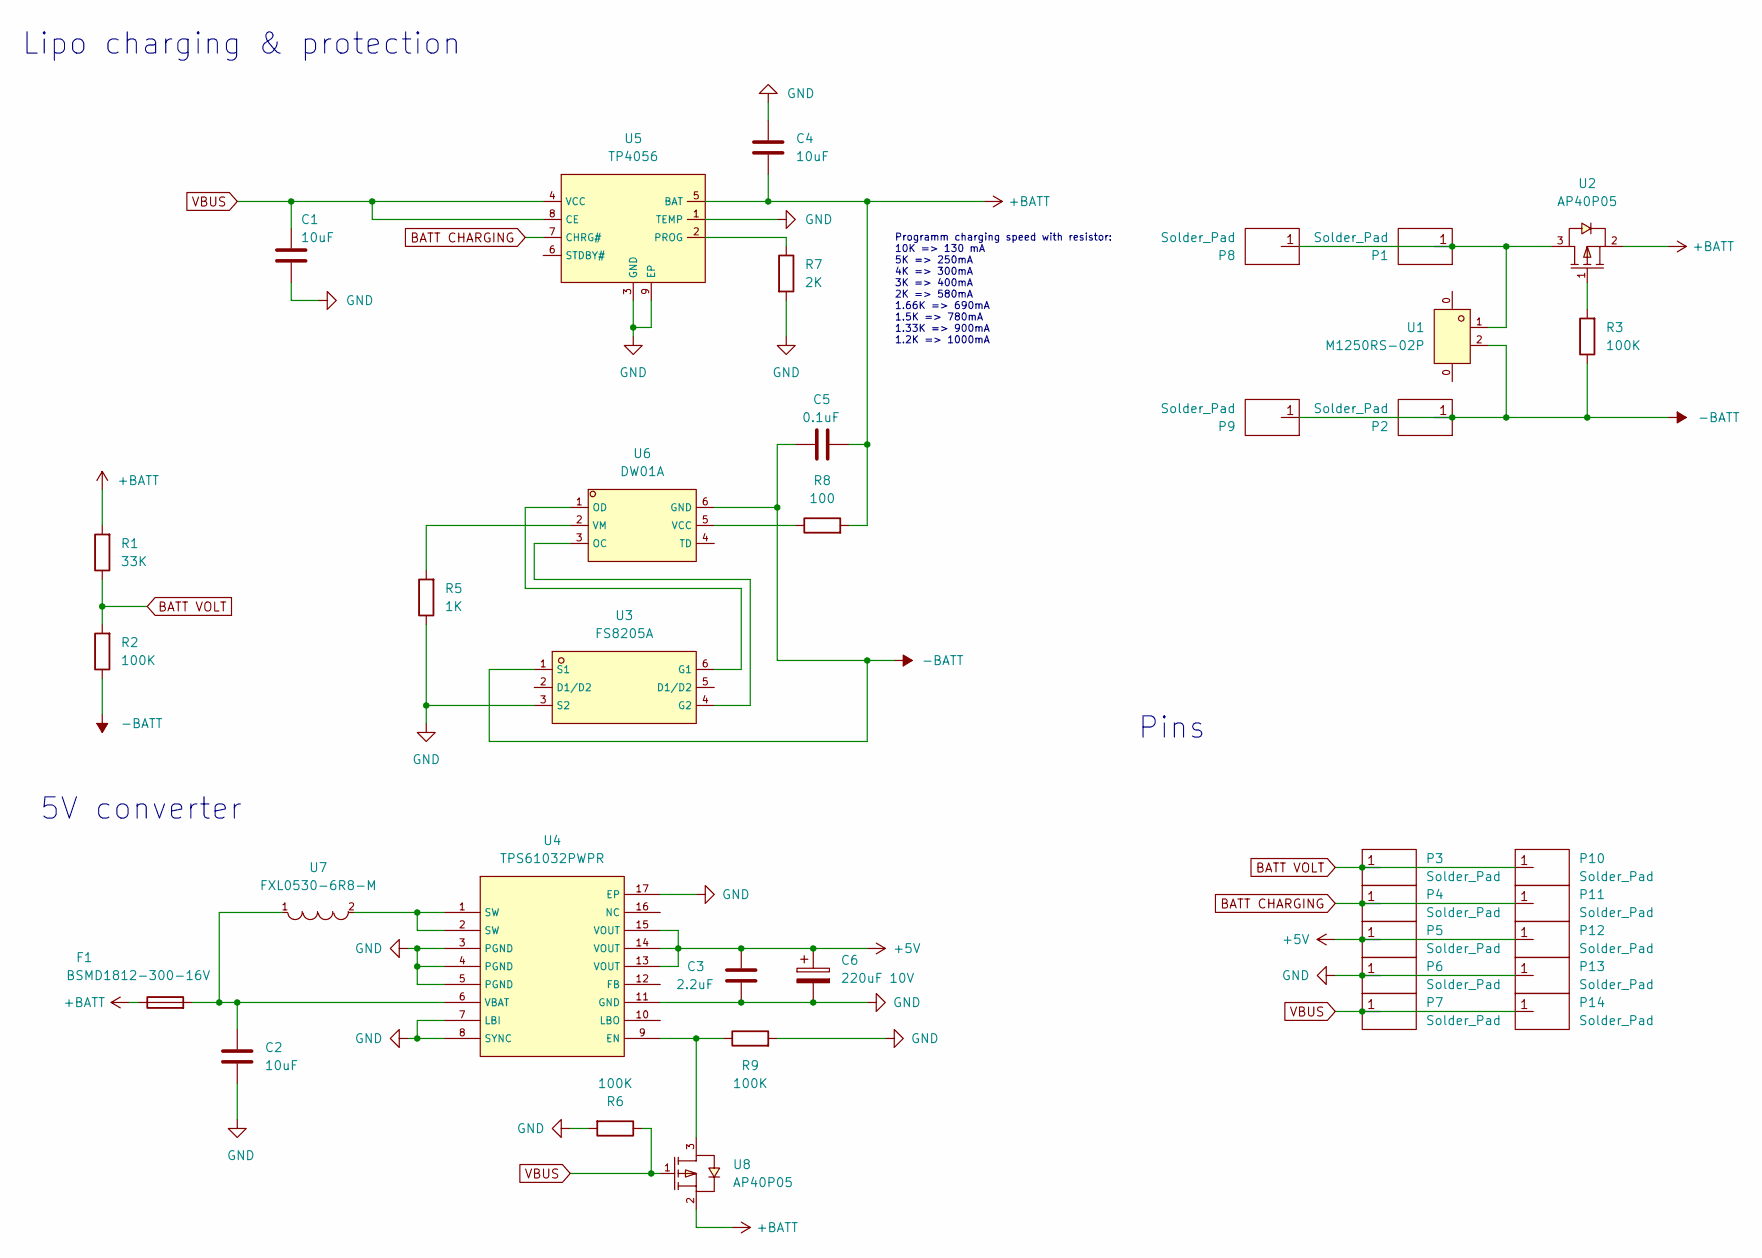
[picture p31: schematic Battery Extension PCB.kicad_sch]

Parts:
C1, C2, C4: 10uF; C_0603_1608Metric; LCSC # C96446
C3: 2.2uF; C_0603_1608Metric; LCSC # C23630
C5: 0.1uF; C_0402_1005Metric; LCSC # C1525
C6: 220uF 10V; CP_Elec_6.3x5.4; LCSC # C267466
F1: BSMD1812-300-16V; Fuse_1812_4532Metric_Pad1.30x3.40mm_HandSolder; LCSC # C883162
P1, P2, P3, P4, P5, P6, P7, P8, P9, P10, P11, P12, P13, P14: Solder_Pad; Solder pad
R1: 33K; R_0402_1005Metric; LCSC # C25779
R2, R3, R6, R9: 100K; R_0402_1005Metric; LCSC # C25741
R5: 1K; R_0402_1005Metric; LCSC # C11702
R7: 2K; R_0402_1005Metric; LCSC # C4109
R8: 100; R_0402_1005Metric; LCSC # C25076
U1: M1250RS-02P; CONN-SMD_2P-P1.25_L4.4-W7.4; LCSC # C481424
U2, U8: AP40P05; SOT-23-3_L2.9-W1.3-P1.90-LS2.4-BR; LCSC # C2886385
U3: FS8205A; SOT-23-6_L2.9-W1.6-P0.95-LS2.8-BR; LCSC # C908265
U4: TPS61032PWPR; HTSSOP-16-1EP_4.4x5mm_P0.65mm_EP3.4x5mm_Mask2.46x2.31mm; LCSC # C88716
U5: TP4056; ESOP-8_L4.9-W3.9-P1.27-LS6.0-BL-EP; LCSC # C382139
U6: DW01A; SOT-23-6_L2.9-W1.6-P0.95-LS2.8-BL; LCSC # C351410
U7: FXL0530-6R8-M; IND-SMD_L5.4-W5.2_FXL0530; LCSC # C177249

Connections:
+5V: C3.2, C6.1, P5.1, P12.1, U4.13 (VOUT), U4.14 (VOUT), U4.15 (VOUT)
+BATT: C4.1, C5.2, F1.1, R1.2, R8.2, U2.2 (S), U5.5 (BAT), U8.2 (S)
-BATT: C5.1, P2.1, P9.1, R2.1, R3.1, U1.2, U3.1 (S1), U6.6 (GND)
BATT CHARGING: P4.1, P11.1, U5.7 (CHRG#)
BATT VOLT: P3.1, P10.1, R1.1, R2.2
GND: C1.1, C2.2, C3.1, C4.2, C6.2, P6.1, P13.1, R5.1, R6.2, R7.2, R9.2, U3.3 (S2), U4.3 (PGND), U4.4 (PGND), U4.5 (PGND), U4.7 (LBI), U4.8 (SYNC), U4.11 (GND), U4.17 (EP), U5.1 (TEMP), U5.3 (GND), U5.9 (EP)
unnamed: C2.1, F1.2, U4.6 (VBAT), U7.1
unnamed: P1.1, P8.1, U1.1, U2.3 (D)
unnamed: R3.2, U2.1 (G)
unnamed: R5.2, U6.2 (VM)
unnamed: R7.1, U5.2 (PROG)
unnamed: R8.1, U6.5 (VCC)
unnamed: R9.1, U4.9 (EN), U8.3 (D)
unnamed: U3.4 (G2), U6.3 (OC)
unnamed: U3.6 (G1), U6.1 (OD)
unnamed: U4.1 (SW), U4.2 (SW), U7.2
VBUS: C1.2, P7.1, P14.1, R6.1, U5.4 (VCC), U5.8 (CE), U8.1 (G)

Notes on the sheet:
Lipo charging & protection
Pins
Programm charging speed with resistor: 10K => 130 mA 5K => 250mA 4K => 300mA 3K => 400mA 2K => 580mA 1.66K => 690mA 1.5K => 780mA 1.33K => 900mA 1.2K => 1000mA
5V converter

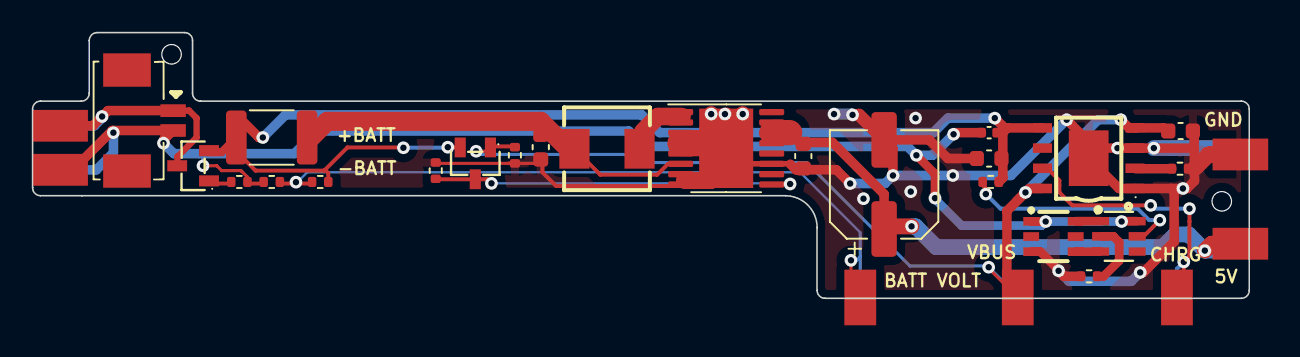
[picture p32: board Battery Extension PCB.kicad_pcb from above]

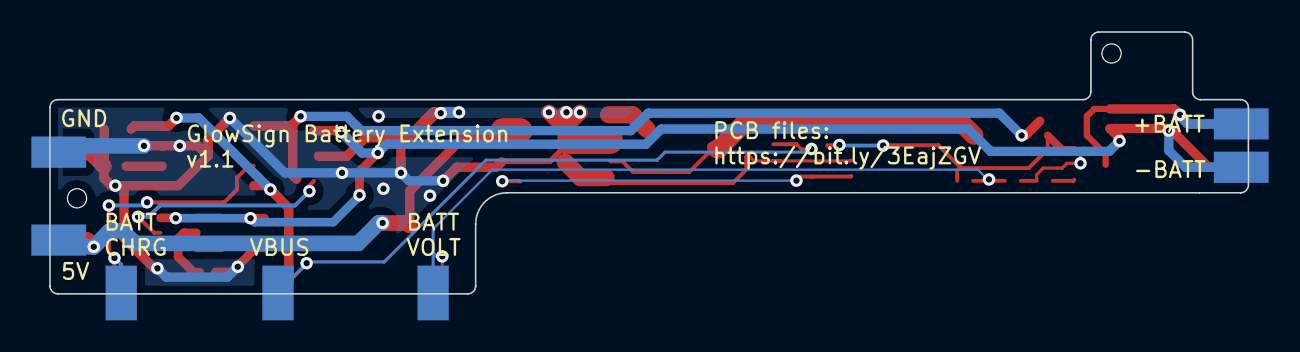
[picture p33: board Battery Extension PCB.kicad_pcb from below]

Board: 2 copper layers, 76.5 x 16.7 mm, 37 parts (7 on the bottom side), 17 nets.

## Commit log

2022-05-06 added pcb files (in dev)
    [AluminumCover-CuBottom.gbr, AluminumCover-CuTop.gbr, AluminumCover-EdgeCuts.gbr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]
2022-05-10 completed first prototype
    [AluminumCover-CuBottom.gbr, AluminumCover-CuTop.gbr, AluminumCover-EdgeCuts.gbr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]
2022-05-13 updated lasercut stencils
2022-06-04 updated mic and levelshifter
    [GlowSignMainPCB.kicad_pcb, GlowSignMainPCB.kicad_sch]
2022-07-10 made improvements and started creating usb-c only version
    [AluminumCover-CuBottom.gbr, AluminumCover-CuTop.gbr, AluminumCover-EdgeCuts.gbr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]
2022-08-06 added new glowsign design
    [AluminumCover-CuBottom.gbr, AluminumCover-CuTop.gbr, AluminumCover-EdgeCuts.gbr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]
2022-08-06 added qr code to cover pcb square
    [GlowSign Aluminum CB square cutout-CuBottom.gbr, GlowSign Aluminum CB square cutout-CuTop.gbr, GlowSign Aluminum CB square cutout-EdgeCuts.gbr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]
2022-08-06 updated cover circle pcb
    [GlowSign Aluminum CB square cutout.kicad_sch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]
2022-08-06 update images
    [GlowSignMainPCB-CuBottom.gbr, GlowSignMainPCB-CuTop.gbr, GlowSignMainPCB-EdgeCuts.gbr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]
2022-08-06 updated schematic
2022-08-10 fixed important mistake... VBUS not connected...
    [GlowSign Aluminum CB square cutout-CuBottom 2.gbr, GlowSign Aluminum CB square cutout-CuTop 2.gbr, GlowSign Aluminum CB square cutout-EdgeCuts 2.gbr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]
2022-08-24 created stencil, updated acrylic plate cutout
    [GlowSignMainPCB-CuBottom 2.gbr, GlowSignMainPCB-CuTop 2.gbr, GlowSignMainPCB-EdgeCuts 2.gbr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]
2022-09-08 separated battery electronics into separate pcb
    [Battery Extension PCB-CuBottom.gbr, Battery Extension PCB-CuTop.gbr, Battery Extension PCB-EdgeCuts.gbr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]
2022-09-09 updated pcb files
    [Battery Extension PCB-B_Cu.gbr, Battery Extension PCB-B_Mask.gbr, Battery Extension PCB-B_Paste.gbr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]
2022-09-10 replaced castallated holes with solder pads
    [Battery Extension PCB-B_Mask.gbr, Battery Extension PCB-CuBottom.gbr, Battery Extension PCB-CuTop.gbr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]
2022-09-10 updated pcb
    [Battery Extension PCB-B_Cu.gbr, Battery Extension PCB-B_Mask.gbr, Battery Extension PCB-B_Paste.gbr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]
2022-10-02 fixed battery extension
    [Battery Extension PCB-CuBottom.gbr, Battery Extension PCB-CuTop.gbr, Battery Extension PCB-EdgeCuts.gbr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]
2022-10-02 cleared folders
    [Battery Extension PCB-B_Cu.gbr, Battery Extension PCB-B_Mask.gbr, Battery Extension PCB-B_Paste.gbr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]
2022-10-05 replaced 0603 with 0402 (battery extension)
    [Battery Extension PCB-CuBottom.gbr, Battery Extension PCB-CuTop.gbr, Battery Extension PCB-EdgeCuts.gbr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]
2022-10-05 fixed schematic naming
    [Battery Extension PCB.kicad_sch]
2022-11-02 updated pcb designs
    [Battery Extension PCB-CuBottom 2.gbr, Battery Extension PCB-CuBottom.gbr, Battery Extension PCB-CuTop 2.gbr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]
2022-11-09 fixed deep sleep power consumption + new LED0
    [GlowSignMainPCB-CuBottom 2.gbr, GlowSignMainPCB-CuBottom.gbr, GlowSignMainPCB-CuTop 2.gbr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]
2022-11-26 updated case design
    [GlowSignMainPCB.kicad_pcb, GlowSignMainPCB.kicad_sch, button.stl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]
